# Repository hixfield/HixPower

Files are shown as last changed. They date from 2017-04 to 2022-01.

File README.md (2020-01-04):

![Build with PlatformIO](https://img.shields.io/badge/build%20with-PlatformIO-orange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)




Hardware (schematic and PCB) and software for a WIFI connected intelligent power switch. It contains a temperature sensor, PIR motion sensor, button (with LED) and buzzer and is based on the ESP8266 microcontroller. Its measurements are pubished via MQTT and it can also be controlled via MQTT. Its part of my home automation system based on a raspberry pi running Mosquitoo, Nodered, InfluxDB and Grafana.

## Improvements

- [ ] Configuration of WIFI SSID/PWD via web interface
- [ ] 3D print design to keep DS18B20 neatly in bottom of the enclosure

## Brief overview

- WIFI connected
- MQTT firmware written using PlatformIO
- plugs directly into the wall socket
- intelligently switches loads upto 2000W on/off
- measures the room temperature
- detects movement (using PIR sensor)
- button on front pannel for manual operation
- led status indication on front panel
- based on popular [ESP8266](http://esp8266.com)

# Hardware
[Click here for hardware information](hardware/README.md)
# Software
[Click here for software information](software/README.md)
# overview
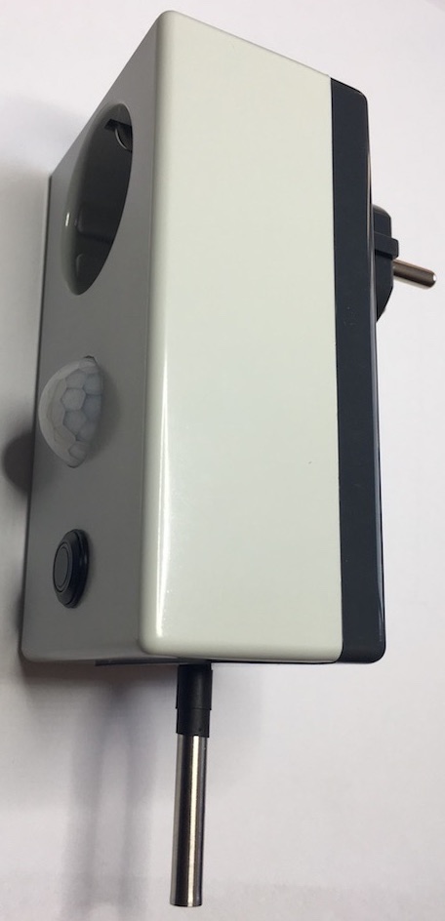
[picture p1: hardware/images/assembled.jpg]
Finished product


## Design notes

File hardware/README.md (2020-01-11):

# PCB
*(click for high resolution image)*

| Top | Bottom |
|---|---|
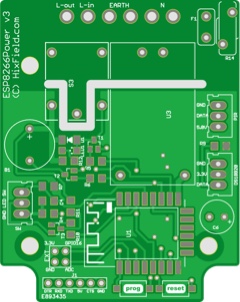
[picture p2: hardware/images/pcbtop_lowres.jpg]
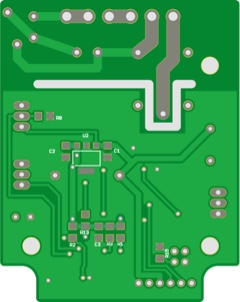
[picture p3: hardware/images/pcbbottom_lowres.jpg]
PCB bottom view
|  |  |

# Schematic
(the repository contains the EagleCAD file)
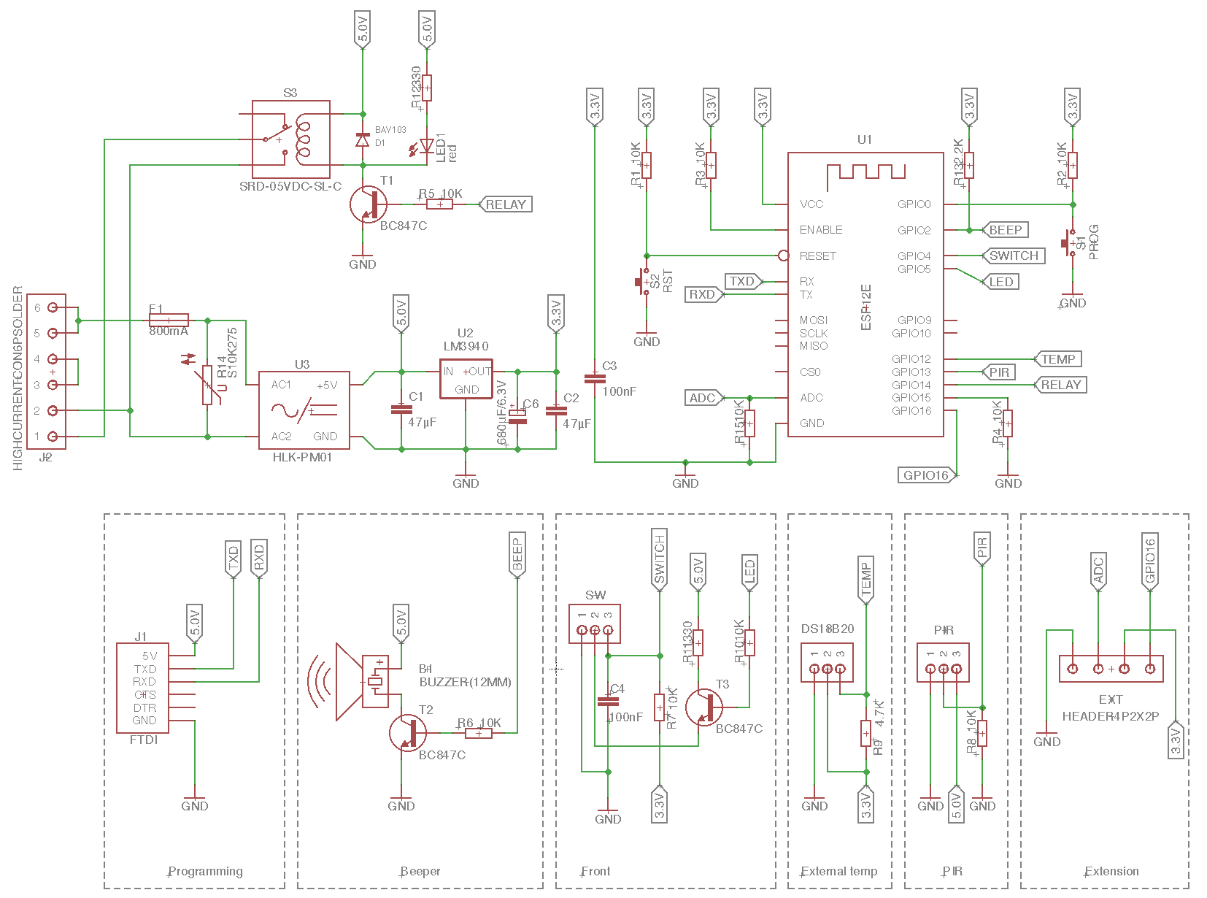
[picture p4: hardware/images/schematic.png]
image of schematic


# Components
## bill of materials
| Qty needed | Qty delivered | Part | Value | Description | picture | 
|---|---|---|---|---|---|
| 2 | 3 | C1, C2 | 47uF | SMD, tantalum capacitor, 1206 | [picture](images/1206_cap_47uf.jpg) | 
| 2 | 3 | C3, C4 | 100nF | SMD, capacitor, 1206 | [picture](images/1206_cap_100nf.jpg) | 
| 1 | 1 | C6 | 680uF / 4V | Through hole, electrolytic capacitor, diameter 8mm, 3.5mm pin spacing | [picture](images/th_cap.jpg) | 
| 10 | 11 | R1, R2, R3, R4, R5, R6, R7, R8, R10, R15 | 10K | SMD, resistor, 1206 | [picture](images/1206_res_10k.jpg) | 
| 1 | 2 | R9 | 4.7K | SMD, resistor, 1206 | [picture](images/1206_res_4.7k.jpg) | 
| 2 | 3 | R11, R12 | 330 | SMD, resistor, 1206 | [picture](images/1206_res_330.jpg) | 
| 1 | 2 | R13 | 2.2K | SMD, resistor, 1206 | [picture](images/1206_res_2.2k.jpg) | 
| 1 | 1 | R14 | S10K275 | Through hole, varistor | [picture](images/th_s10k275.jpg) | 
| 1 | 1 | F1 | 800mA | "Through hole, fuse, 8.35mm x 4 mm, 0.2"" (5.08mm) pin spacing " | [picture](images/th_fuse_800ma.jpg) | 
| 1 | 2 | LED1 | Red | SMD, led, 1206 | [picture](images/1206_led_red.jpg) | 
| 1 | 2 | D1 | BAV103 | SMD, diode, SOD80 | [picture](images/sod80_bav103.jpg) | 
| 3 | 4 | T1, T2, T3 | BC847C | SMD, NPN Transistor, SOT23 | [picture](images/sot23_bc847c.jpg) | 
| 1 | 1 | B1 | 5V | "Through hole, buzzer, diameter 12mm, 0.3"" (7.62mm) pin spacing" | [picture](images/th_buzzer.jpg) | 
| 1 | 1 | U1 | ESP12E | SMD, ESP12E module | [picture](images/esp12e.jpg) | 
| 1 | 1 | U2 | LM3940 | SMD, Low drop voltage regulator, SOT223 | [picture](images/sot223_lm3940.jpg) | 
| 1 | 1 | U3 | HLK-PM01 | Through hole, power module, HiLink HLK-PM01 | [picture](images/th_hlk-pm01.jpg) | 
| 1 | 1 | J1 | FTDI | "Through hole, header female,  6P,  0.1"" (2.54mm) pin spacing" | [picture](images/th_ftdi.jpg) | 
| 2 | 2 | S1, S2 | PROG, RST | SMD Push button | [picture](images/micropushbutton.jpg)  | 
| 1 | 1 | S3 | SRD-05VDC-SL-C | Through hole, Relay SRD-05VDC-SL-C | [picture](images/relay.jpg) | 
| 2 | 2 | PIR, SW | XH3P | Through hole, Connector male XH3P straight | [picture](images/th_xh3pmale.jpg) | 
| 1 | 1 | DS18B20 temp sensor encased | | Module, DS18B20 temp sensor encased | [picture](images/ds18b20.jpg) | 
| 1 | 1 | PIR Module | | Module, PIR | [picture](images/pirmodule.jpg) | 
| 1 | 1 | Switch with led | | Switch with led | [picture](images/pushbutton.jpg) | 
| 2 | 2 | XH3P female no pins | | XH3P female no pins | [picture](images/xh3pfemalesolder.jpg) | 
| 2 | 2 | XH3P wire 10cm [pin -> solder], black | | XH3P wire 10cm [pin -> solder], black | [picture](images/xh3pfemalesolder.jpg) | 
| 1 | 1 | XH3P wire 10cm [pin -> solder], red | | XH3P wire 10cm [pin -> solder], red | [picture](images/xh3pfemalesolder.jpg) | 
| 1 | 1 | XH3P wire 10cm [pin -> solder], yellow | | XH3P wire 10cm [pin -> solder], yellow | [picture](images/xh3pfemalesolder.jpg) | 
| 2 | 2 | XH3P wire 10cm [pin -> solder], white | | XH3P wire 10cm [pin -> solder], white | [picture](images/xh3pfemalesolder.jpg) | 
| 1 | 1 | Case | | Case BOPLA 43432501, predrilled | [picture](images/case.jpg) | 
| 1 | 1 | PCB | | Custom PCB | [picture](images/pcb.jpg) | 
| 2 | 2 | Cable lug round M3 | | Cable lug round M3 | [picture](images/cablelugroundm3.jpg)  | 
| 1 | 1 | Cable lug fork M4 | | Cable lug fork M4 | [picture](images/cablelugforkm4.jpg) | 
| 1 | 1 | Heat shrink tubing 1,5mm, 2.5mm, 6mm, 8mm| | Heat shrink tubing 1,5mm, 2.5mm, 6mm, 8mm | [picture](images/heatshrinktubing.jpg) | 
| 3 | 3 | PCB Fixation screw | | Allen screw, inox, M3 x 6mm thread length | [picture](images/screw.jpg) | 
| 1 | 1 | 1.5mm2 x 55mm mains wire brown | | 1.5mm2 x 55mm mains wire brown | [picture](images/mainswire.jpg) | 
| 1 | 1 | 1.5mm2 x 55mm mains wire blue | | 1.5mm2 x 55mm mains wire blue | [picture](images/mainswire.jpg) | 
| 1 | 1 | 1.5mm2 x 55mm mains wire yellow/green | | 1.5mm2 x 55mm mains wire yellow/green | [picture](images/mainswire.jpg) | 

## overview
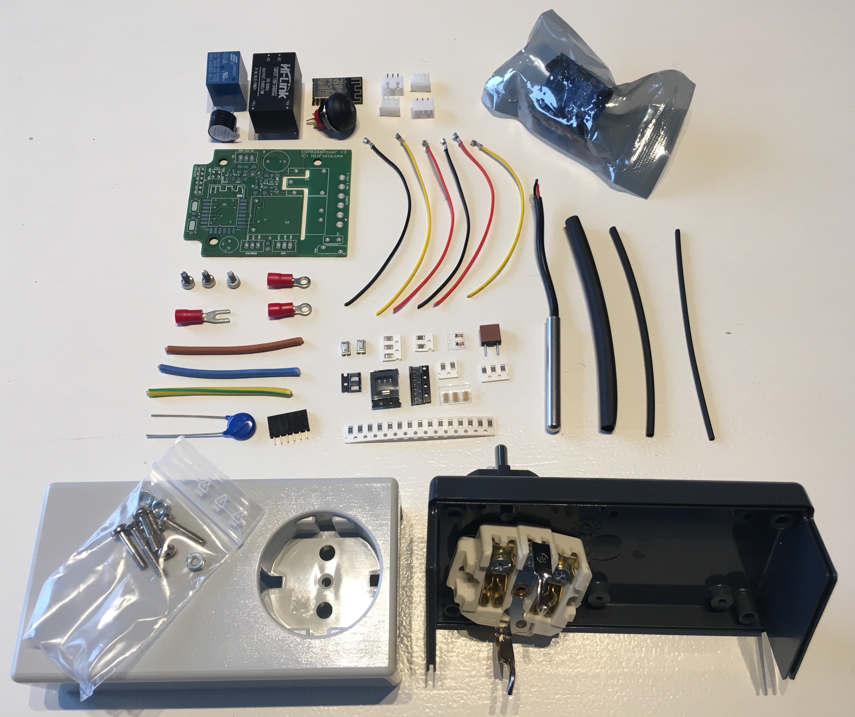
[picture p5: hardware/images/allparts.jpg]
all parts


# Assembly instructions
## soldering of the PCB
### Step 0: BC847 transistors
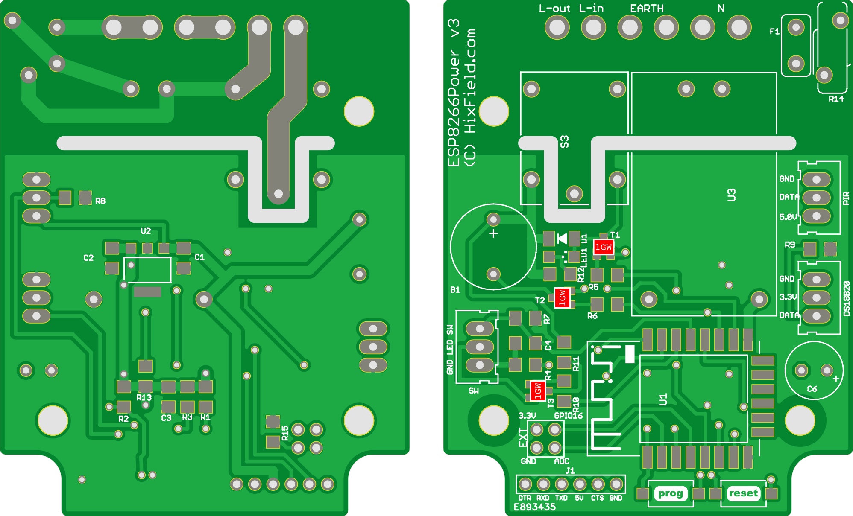
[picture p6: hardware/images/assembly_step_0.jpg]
assembling step 1

### Step 1: 10K resistors
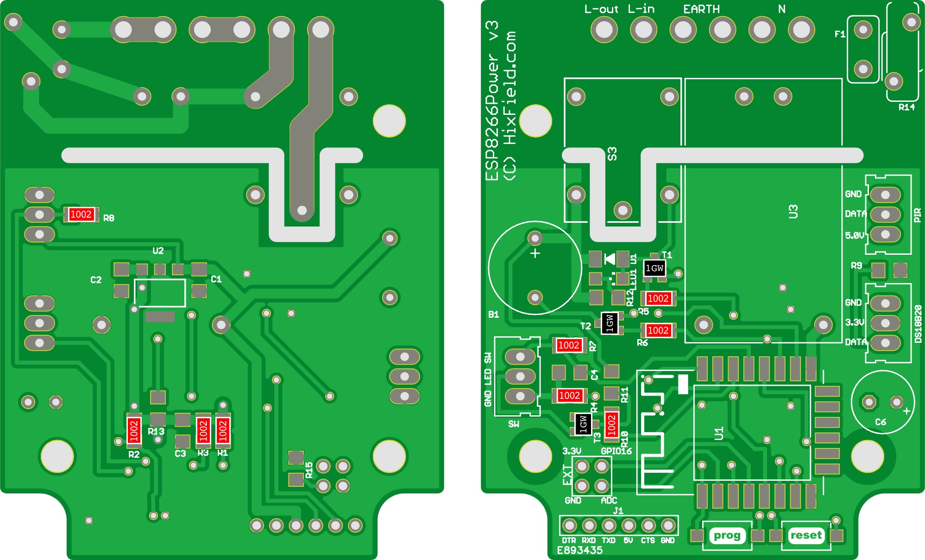
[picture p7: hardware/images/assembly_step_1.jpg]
assembling step 1

### Step 2: 4.7K resistors
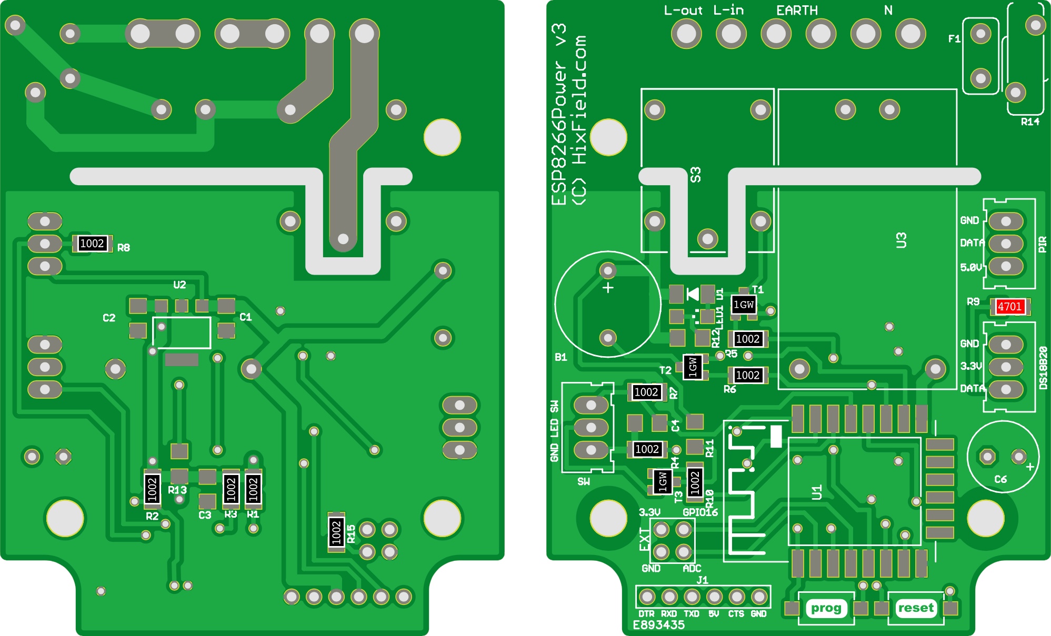
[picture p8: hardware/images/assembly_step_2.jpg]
assembling step 1

### Step 3: 330 resistors
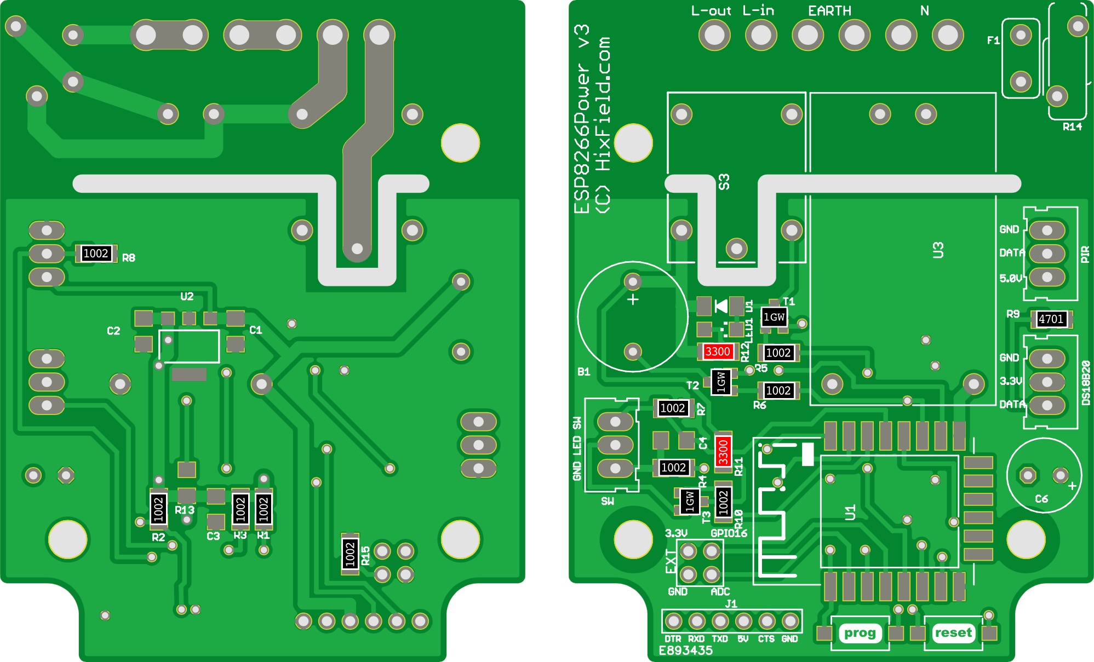
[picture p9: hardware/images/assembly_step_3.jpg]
assembling step 1

### Step 4: 2.2K resistors
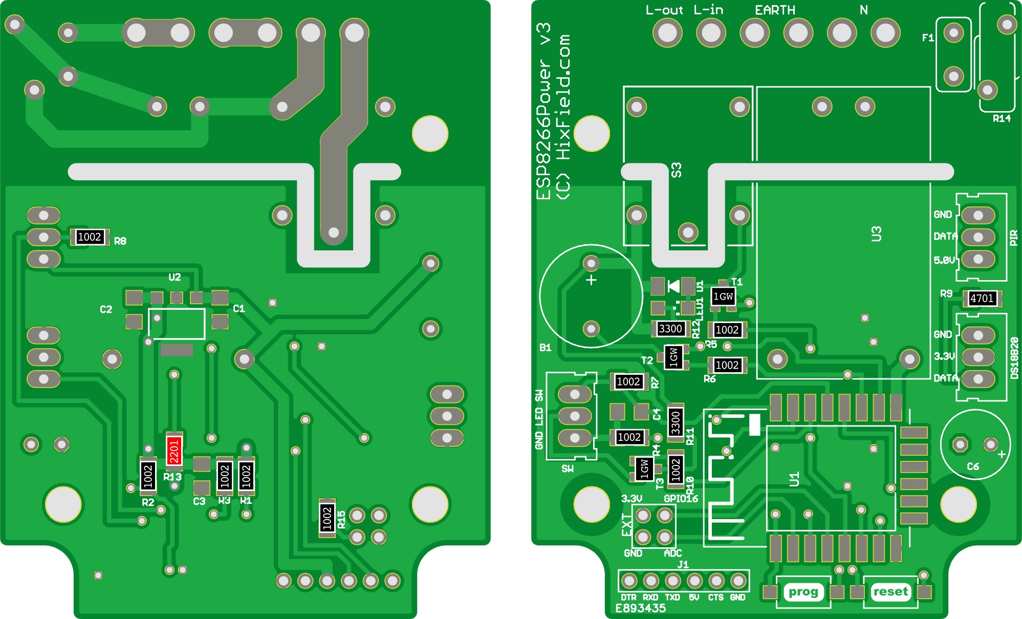
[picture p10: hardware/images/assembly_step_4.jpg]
assembling step 1

### Step 5: 100nF capacitors
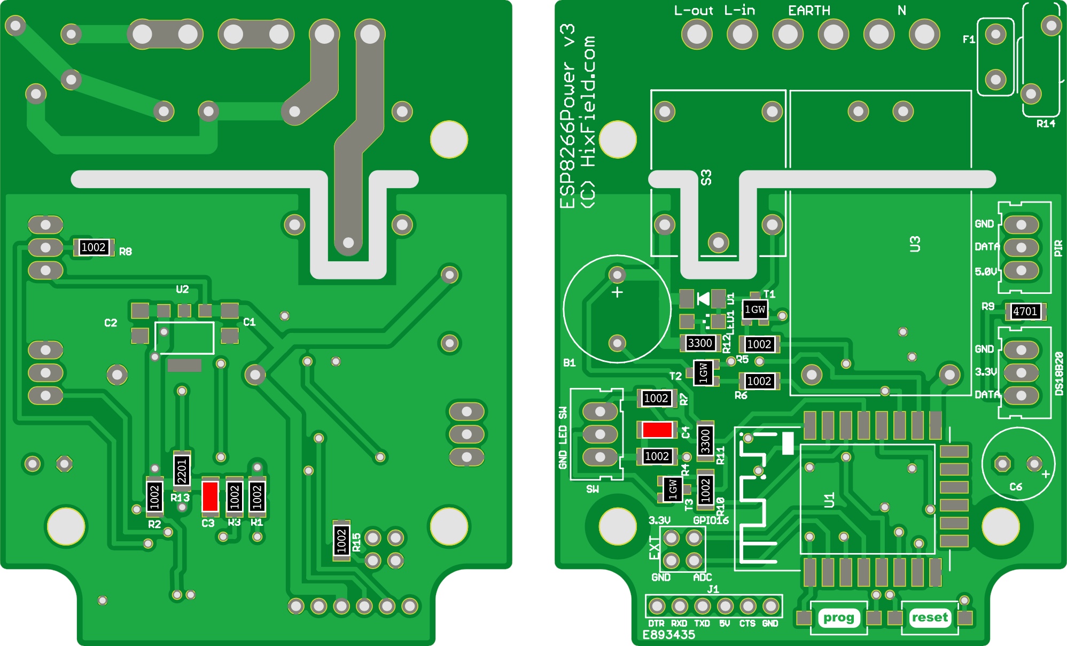
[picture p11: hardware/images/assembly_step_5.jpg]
assembling step 1

### Step 6: 47uF tantalum capacitors
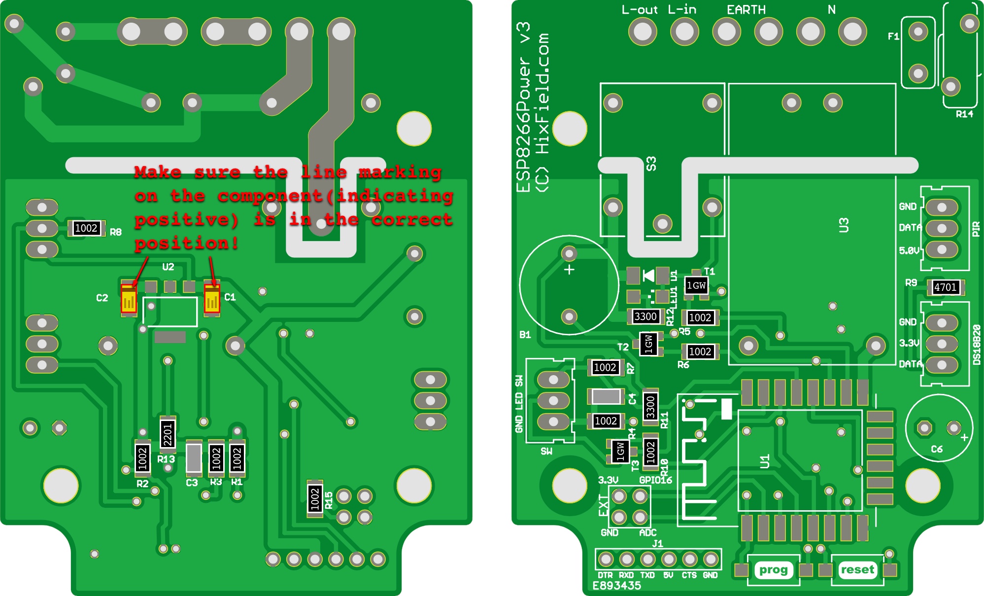
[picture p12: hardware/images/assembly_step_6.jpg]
assembling step 1

### Step 7: LM3940 voltage controller
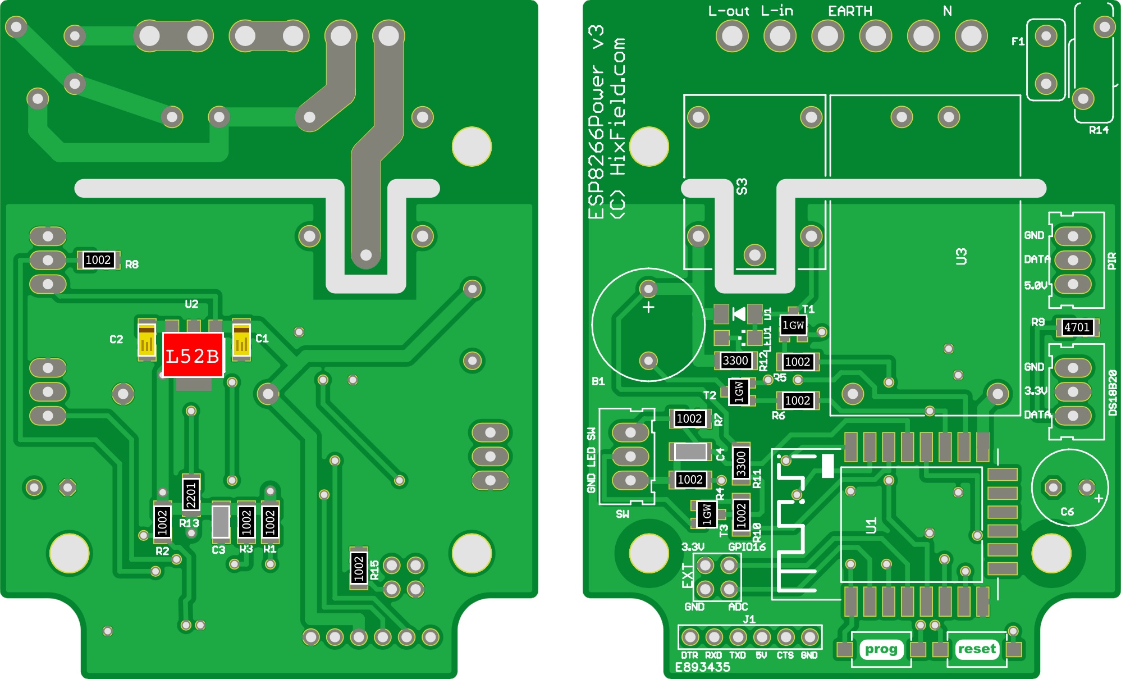
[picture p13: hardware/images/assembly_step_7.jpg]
assembling step 1

### Step 8: LED
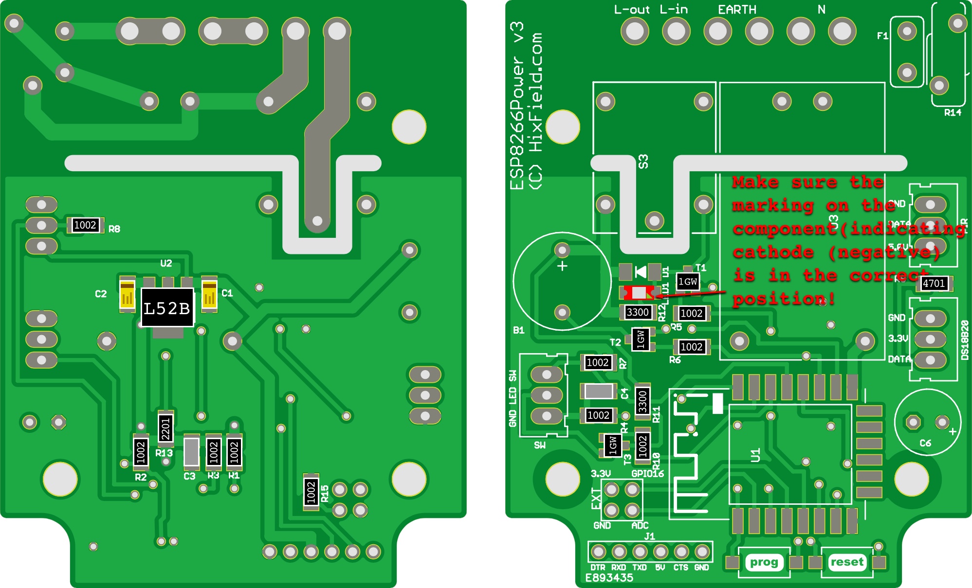
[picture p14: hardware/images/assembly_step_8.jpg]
assembling step 1

### Step 9: Diode
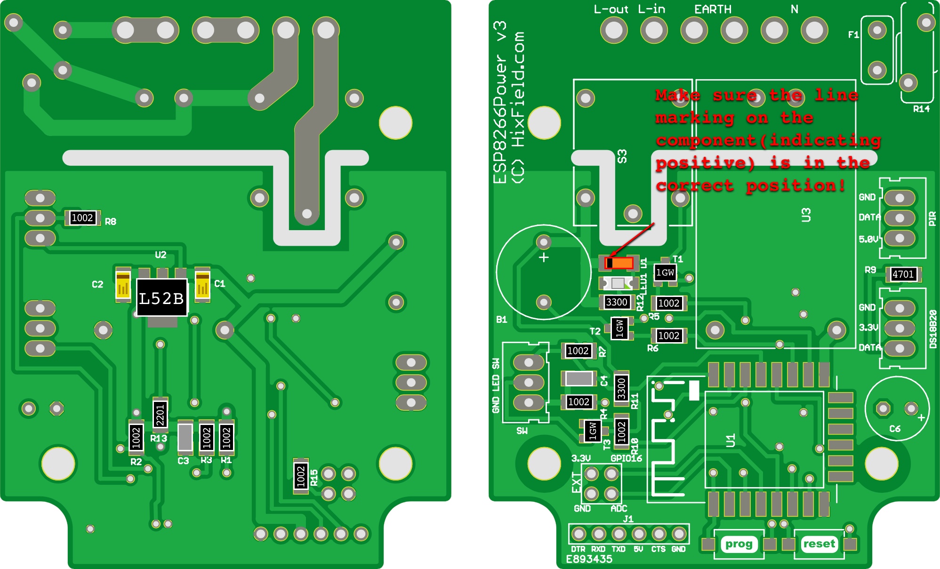
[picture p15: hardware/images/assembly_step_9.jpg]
assembling step 1

### Step 10: ESP12E
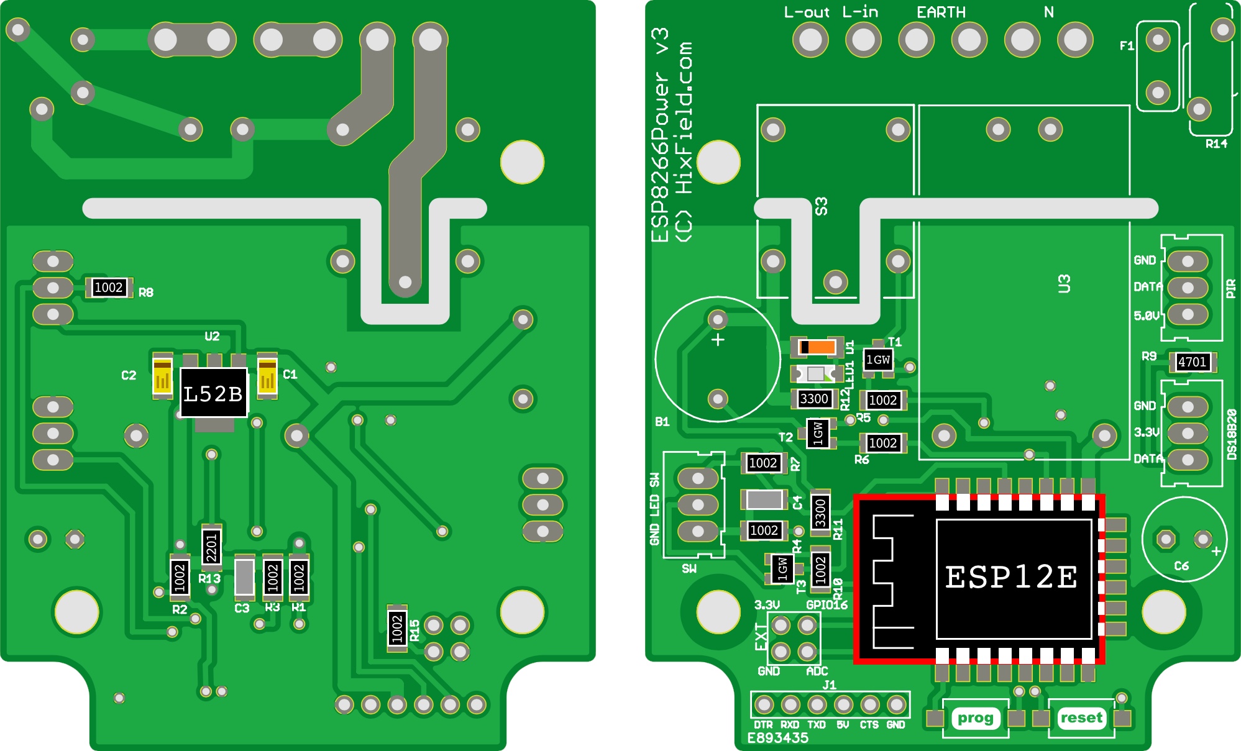
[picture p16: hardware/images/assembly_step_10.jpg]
assembling step 1

### Step 11: Push buttons
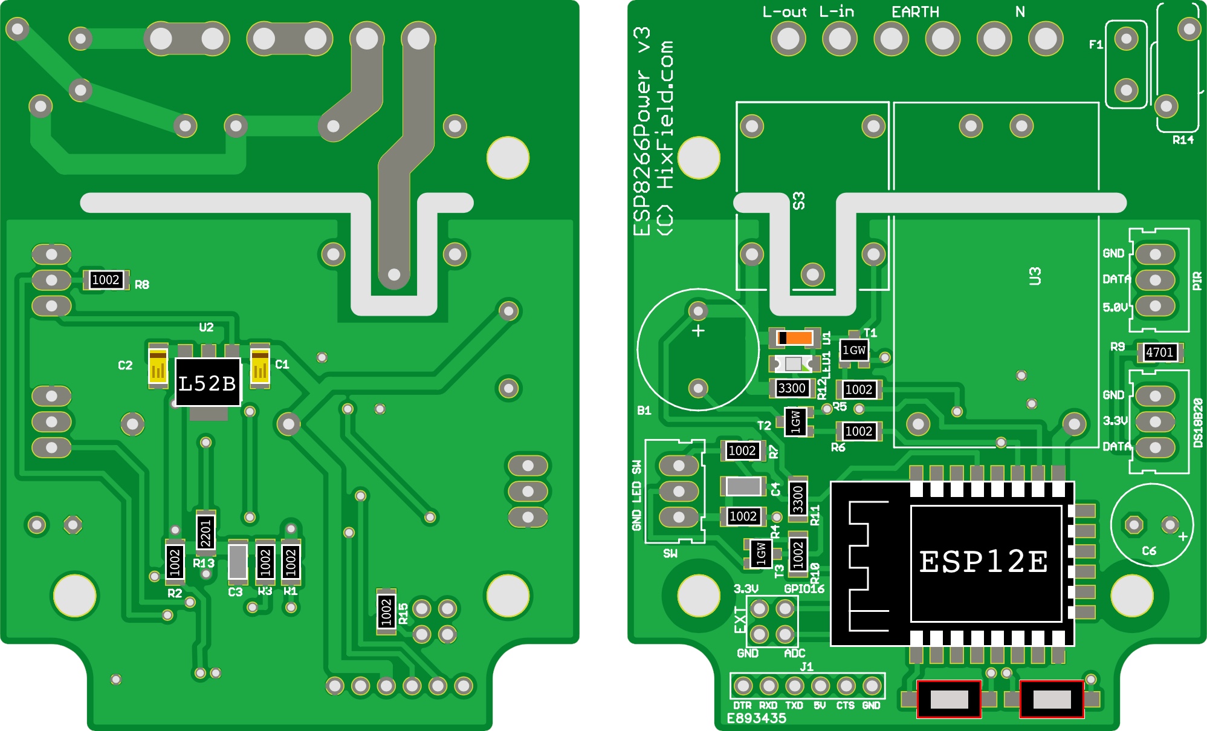
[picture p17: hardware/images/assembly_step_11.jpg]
assembling step 1

### Step 12: 680uF capacitor 
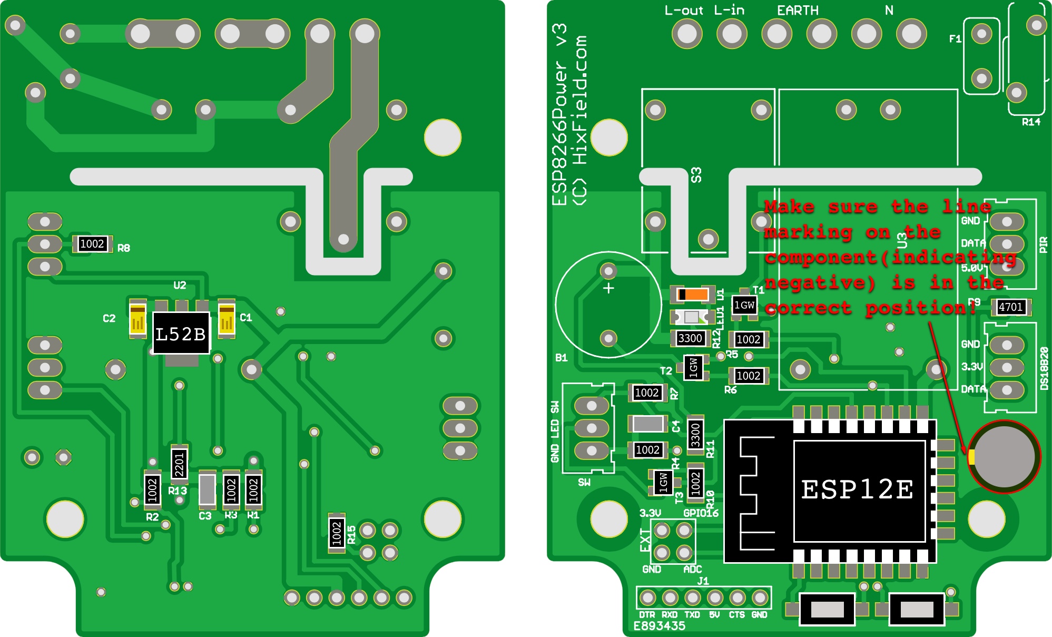
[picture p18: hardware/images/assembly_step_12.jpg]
assembling step 1

### Step 13: connectors
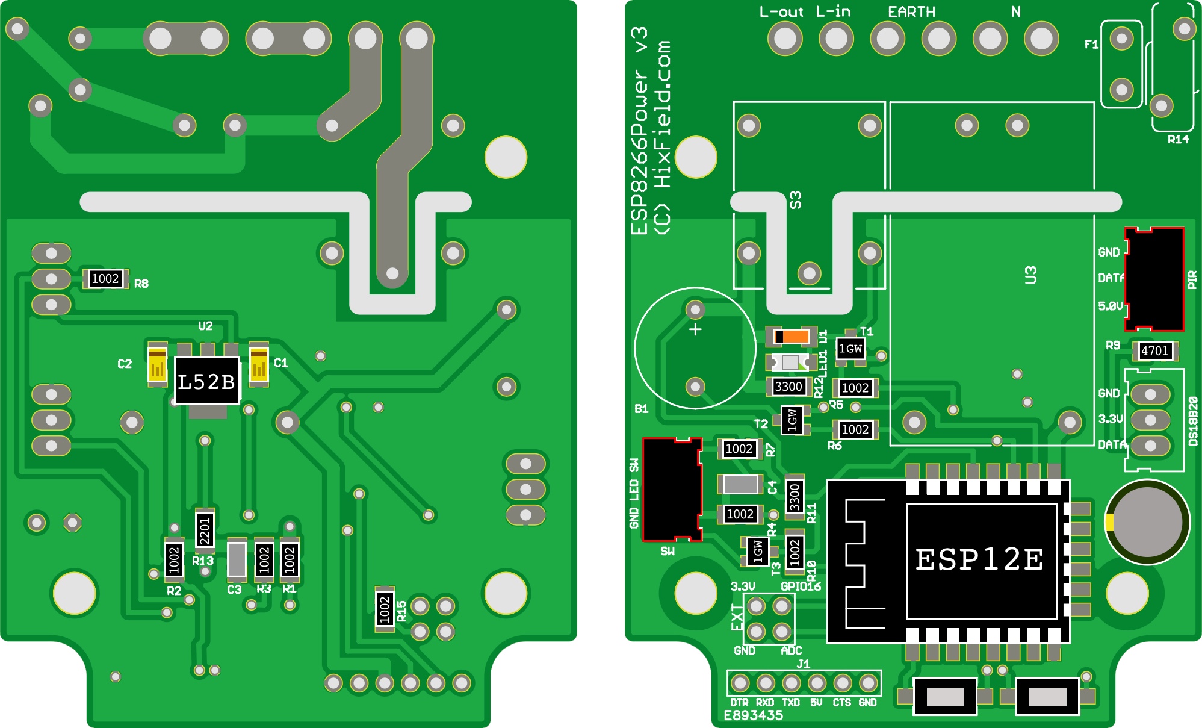
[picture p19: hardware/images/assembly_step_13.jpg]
assembling step 1

### Step 14: buzzer
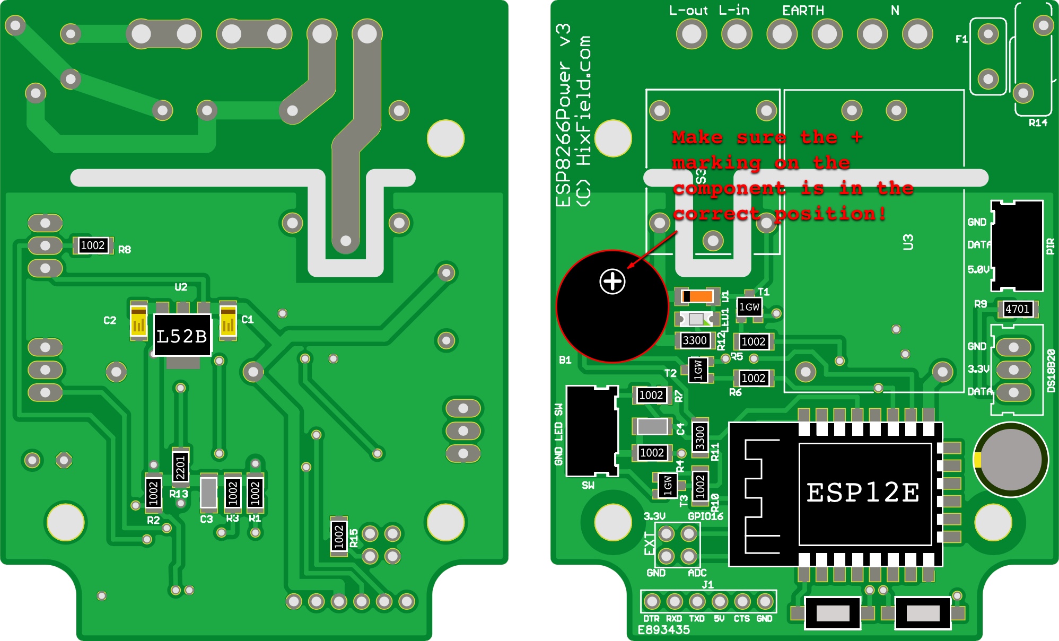
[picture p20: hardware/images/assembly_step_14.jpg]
assembling step 1

### Step 15: relay
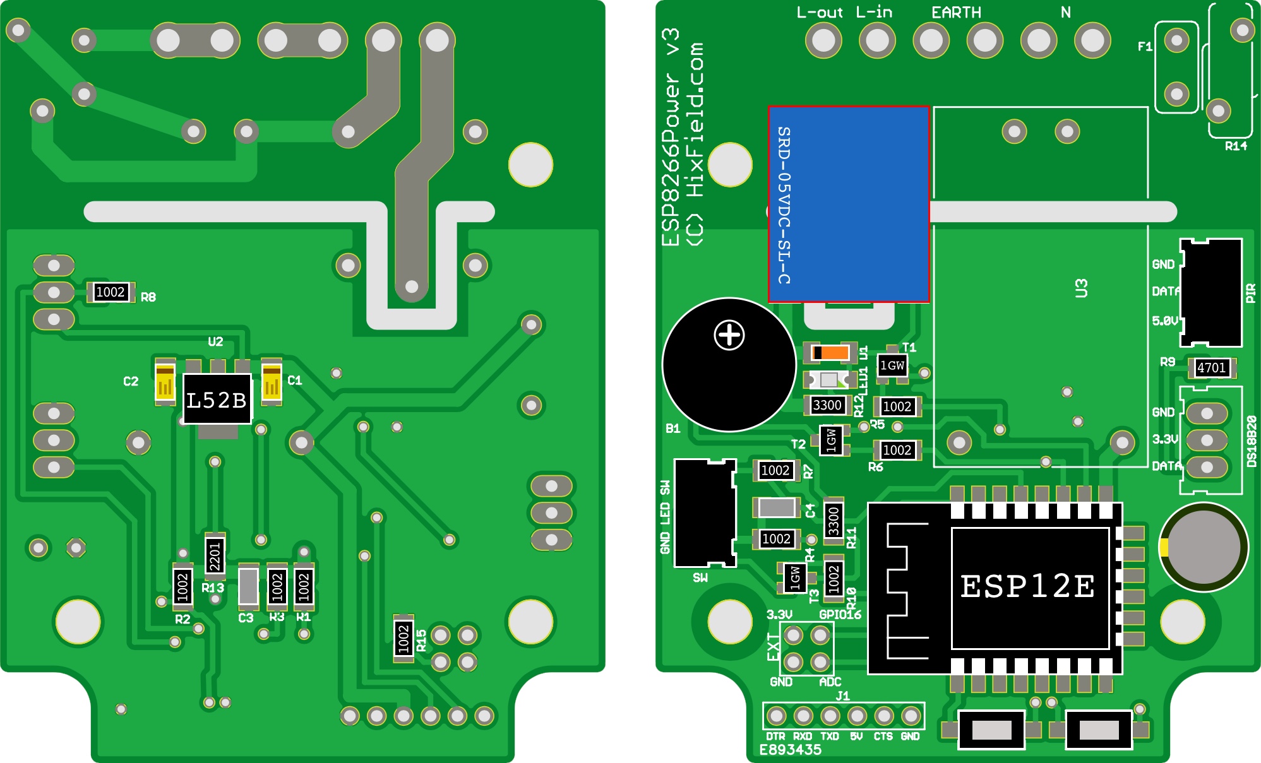
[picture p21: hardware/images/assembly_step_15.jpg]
assembling step 1

### Step 16: power supply
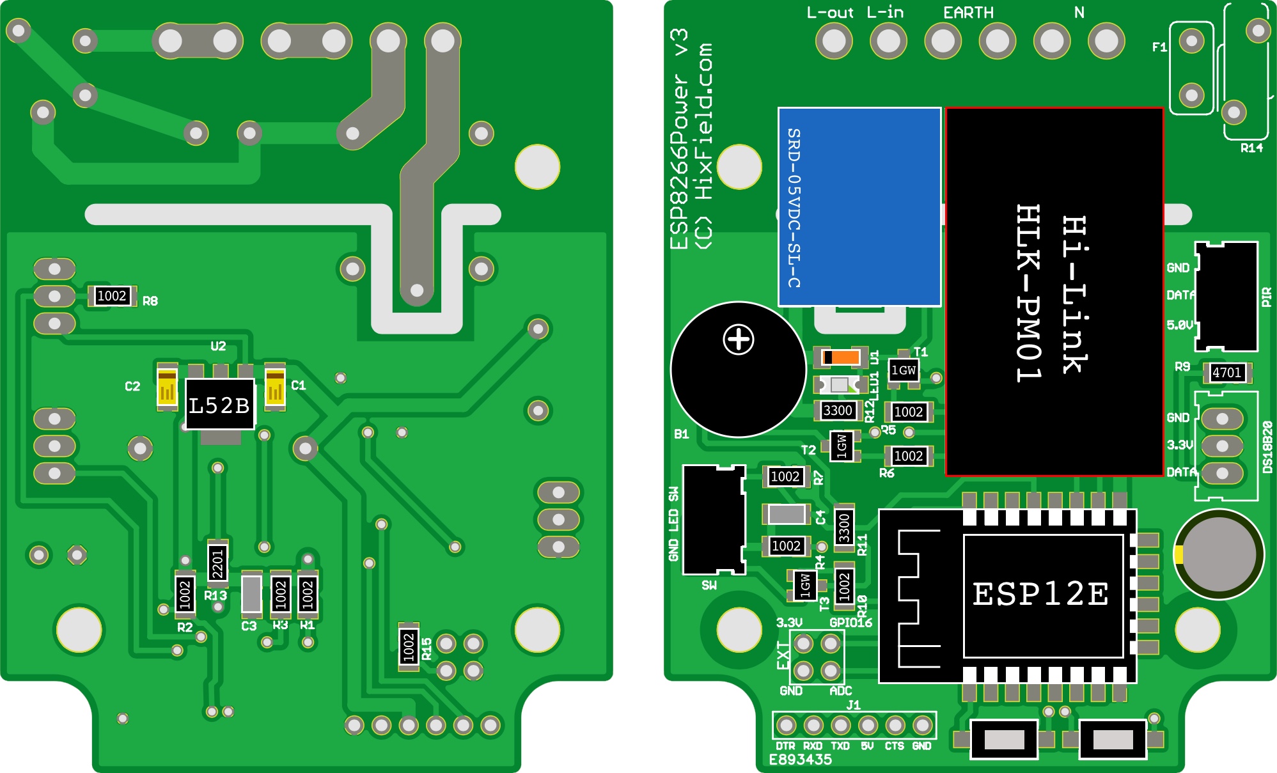
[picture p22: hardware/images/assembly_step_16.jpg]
assembling step 1

### Step 17: FTDI connector
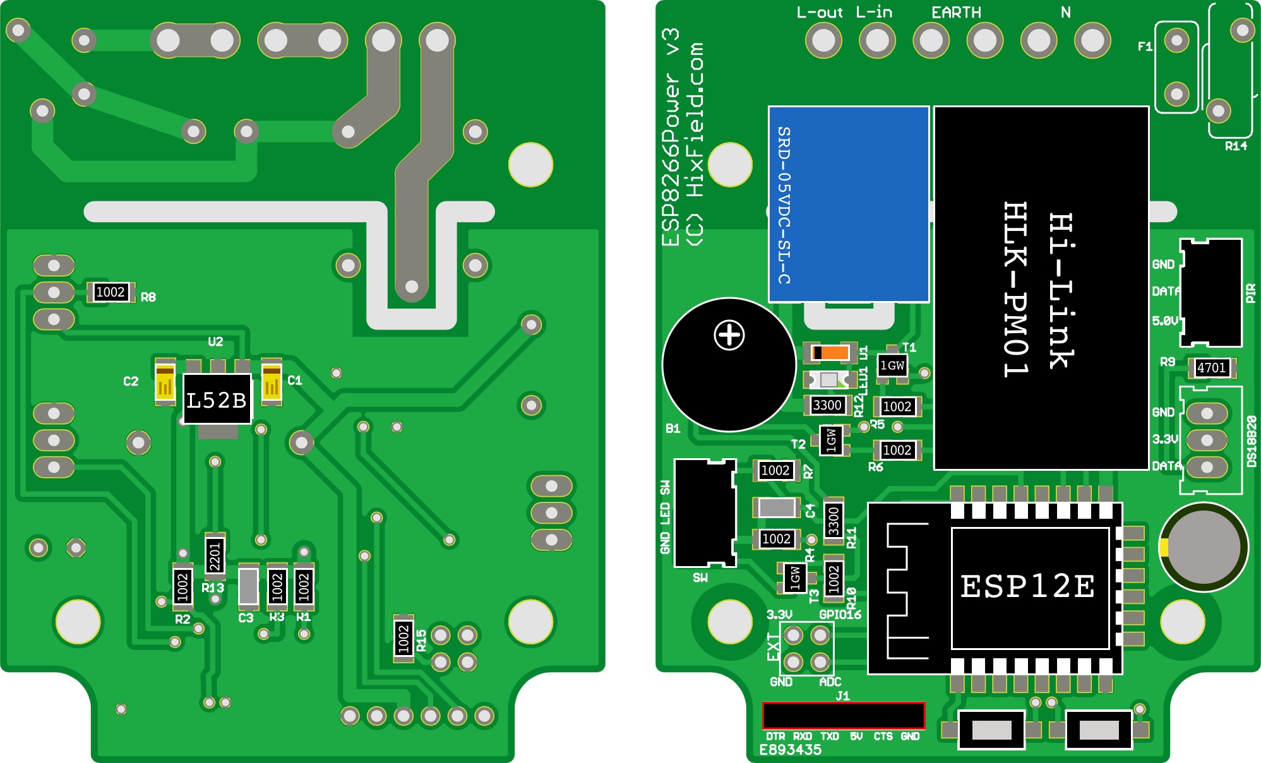
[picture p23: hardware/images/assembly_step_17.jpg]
assembling step 1

### Step 18: Fuse
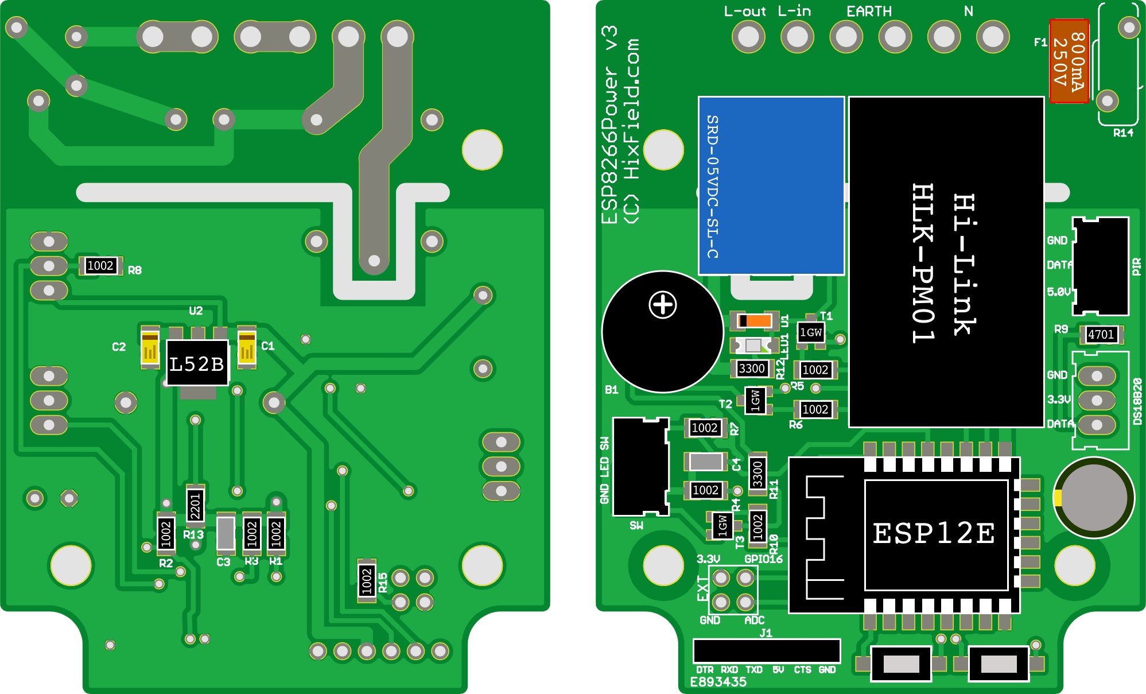
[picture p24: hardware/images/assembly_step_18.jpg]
assembling step 1

### Step 19: Varistor
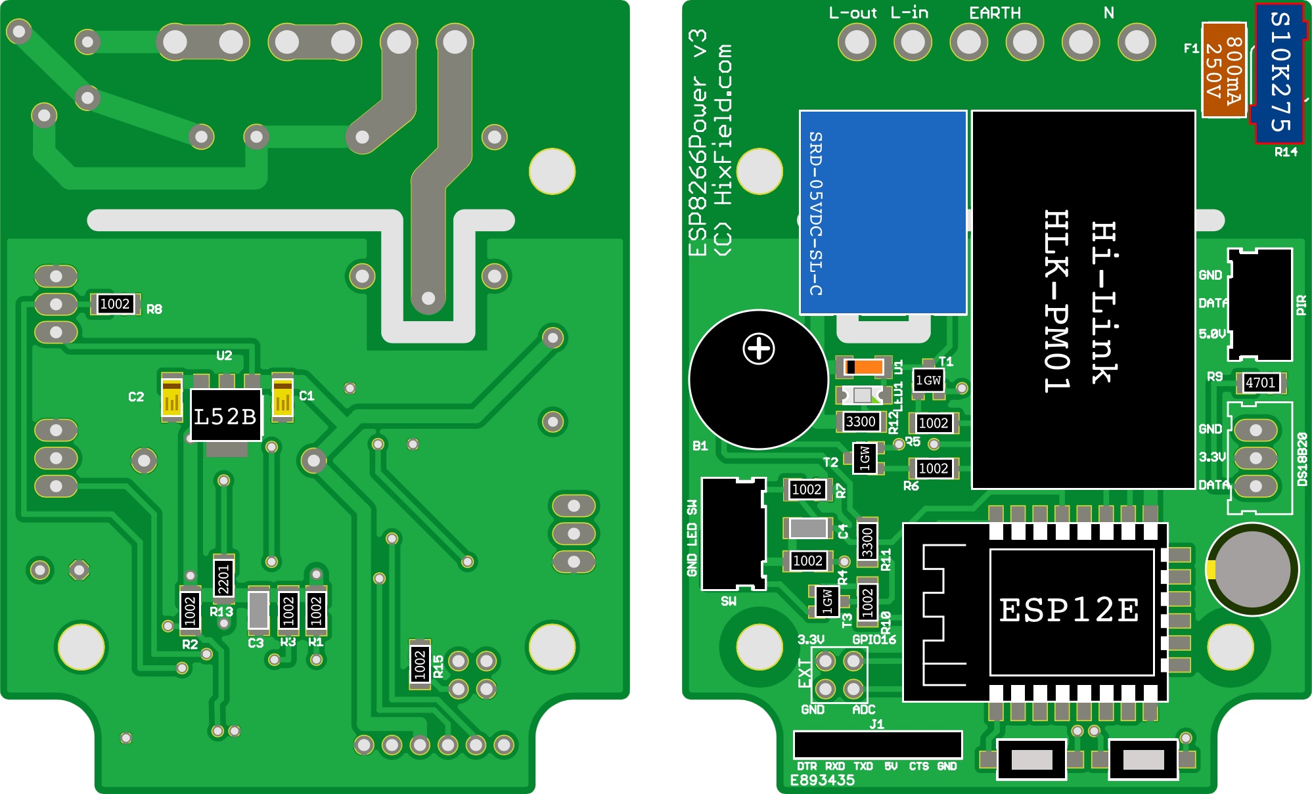
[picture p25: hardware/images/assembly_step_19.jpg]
assembling step 1

## Assemble main wires
### Step 29: neutral (blue) and live (brown) mains connection wires
1.5 mm² x 70 mm
assembling step 1
### Step 21: earthing wire (yellow/green)
assembling step 1
## Assemble push button
### Step 22: prepare wires
assembling step 1
### Step 23: connect (black) GND wire
assembling step 1
### Step 24: connect (white) SWITCH wire
assembling step 1
### Step 25: connect (yellow) + LED wire
assembling step 1
### Step 26: shrink and put in housing
assembling step 1
## Assemble PIR
### Step 27: prepare and connect wires
assembling step 1
### Step 28: shrink and put in housing
assembling step 1
### Step 29: adjust settings
assembling step 1

- refer to [HC-SR501 Motion Sensor Tutorial]([http://henrysbench.capnfatz.com/henrys-bench/arduino-sensors-and-input/arduino-hc-sr501-motion-sensor-tutorial/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]) http://henrysbench.capnfatz.com/henrys-bench/arduino-sensors-and-input/arduino-hc-sr501-motion-sensor-tutorial/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
- trigger selection jumper => recommended REPEATABLE TRIGGER
- set correct sensitivy and delay setings (variable resistors)
 * Sensitivity Adjust => recommended MIDDLE
 * Time Delay Adjust  => recommended MINIMUM

## Prepare temperature sensor
assembling step 1

##Build PCB in the case
- solder the temperature sensor to the pcb
 - red = 3.3v
 - black = GND
 - blue = DATA  
- put PCB in case and fix using the screws
- put the temp sensor through the hole in the case
- connect the mains and earth wires to the power pins in the case
- cut 10 mm of heat shrink tube 8mm and slide it over the temperature sensor to fix it

## Programming via the FTDI connector
If you want to program manually via the FTDI connector:

- DO NOT 	PLUG THE DEVICE IN THE POWER !
- put in your USB -> SERIAL connector
- Push the onboard buttons in the correct sequence:
 - push and keep pushing the PROG button
 - push the RESET (while keeping PROG pressed)
 - release both butons
- De device is now in programming mode 	

##Assemble front
- mount the push button in the front of the case
- fix / glue the PIR sensor in the front of the case

##Assemble the device
- assemble front and back of case
 - connect push button connector
 - connect PIR connector
- close case and put in the screws  

# Packaging
- 330 gr (including box)
- ideal box would be approx 70mm x 130mm x 100 mm
# Case preparation
PCB top view

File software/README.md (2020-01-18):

![Build with PlatformIO](https://img.shields.io/badge/build%20with-PlatformIO-orange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)


# HixPower

Software for a WIFI connected intelligent power switch. It contains a temperature sensor, PIR/radar motion sensor, button (with LED) and buzzer and is based on the ESP8266 microcontroller. Its measurements are pubished via MQTT and it can also be controlled via MQTT. Its part of my home automation system based on a raspberry pi running Mosquitoo, Nodered, InfluxDB and Grafana.

## High voltage

This device uses high mains voltage! Remove it from the mains power (socket) while programming via the onboard FTDI connector. During programming and debugging the device can safely be powered via the FTDI with 5V. It will boot and work normally drawing power over the FTDI. This way you can also debug using the onboard serial port for the ESP8266 environment.

Make sure your FTDI programmer can deliver the required power. Mine, a chinese clone "Deek-Robot" had no problem at all.
Once initially flashed the device can be updated Over The Air (OTA) (as supported by this firmware).

## MQTT

### Publishing

```
{room}
   └─── HixCO2
           └─── {deviceTag}
                     └─── device
                     │       └─── count
                     │       └─── room
                     │       └─── device_type
                     │       └─── device_version
                     │       └─── device_tag
                     │       └─── device_name
                     │       └─── wifi_ssid
                     │       └─── wifi_ip
                     │       └─── desired_temperature
                     │       └─── auto_switchoff_seconds
                     │       
                     └─── status
                     │       └─── count
                     │       └─── wifi_rssi
                     │       └─── temperature
                     │       └─── motion_detected
                     │       └─── switch_pressed
                     │       └─── beeper_on
                     │       └─── output_allowed
                     │       └─── output_on
                     │       └─── auto_switchoff_seconds_left
                     │
                     └─── subscribe
                     │       └─── desired_temperature
                     │       └─── auto_switchoff_seconds
                     │       └─── output_toggle
                     │
                     └─── influxdb
```

### Subscribing
This device listens to the above depicted topics to set the desired temperature, auto switch off timeout and you can switch it on/off (toggle).

#### `influxdb` topic publishing contents
To make the import in the influxdb from Node-RED as easy as possible the `influxdb` topic publishes a json document that can immediatly imported using the `influxdb in` node.
They only thing required is to convert it to a json object via the `To json` node.
Node-RED influxDB import

Following the `influxdb in` node the json is an array where:

- the first element contains the measurements
- the second element contains the tags

```
[  
   {  
      "wifi_rssi"                   : -45,
      "temperature"                 : 45,
      "motion_detected"             : true,
      "switch_pressed"              : false,
      "beeper_on"                   : false,
      "output_allowed"              : true,
      "output_on".                  : true,
      "auto_switchoff_seconds_left" : 768
   },
   {  
      "device_type".                 : "HixPower",
      "device_version".              : "2.2.9",
      "device_tag".                  : "heating",
      "room"                         : "bathroom",
      "wifi_ssid".                   : "public_wifi",
      "desired_temperature".         : "public_wifi",
      "auto_switchoff_seconds_left". : "public_wifi"
   }
]
```

## Configuration web interface

Config web interface

* Once connectted to the WIFI a normal browser can be used to configure the MQTT details.
* Just go the the device's ip address with your browser
* Password is intitially set as `bornem1973`.
* At this moment the WIFI SSID and password are hardcoded in the src/secret.cpp file

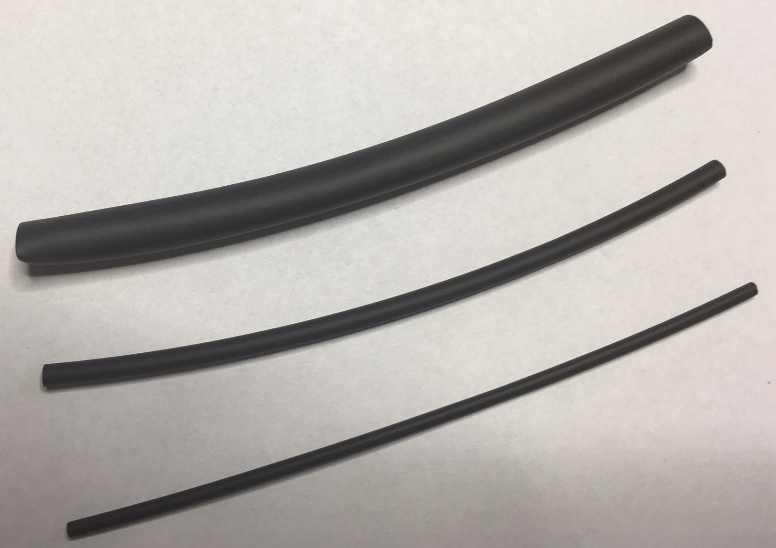
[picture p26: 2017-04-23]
hardware/images/heatshrinktubing.jpg

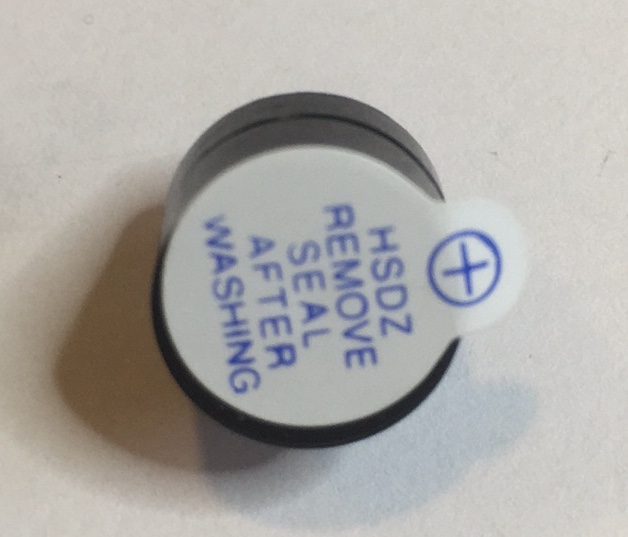
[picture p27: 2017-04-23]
hardware/images/th_buzzer.jpg

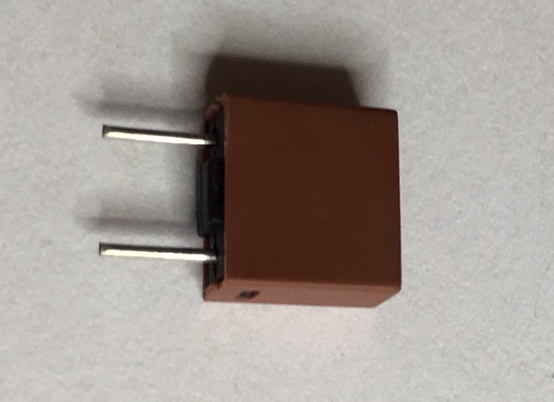
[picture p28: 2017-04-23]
hardware/images/th_fuse_800ma.jpg

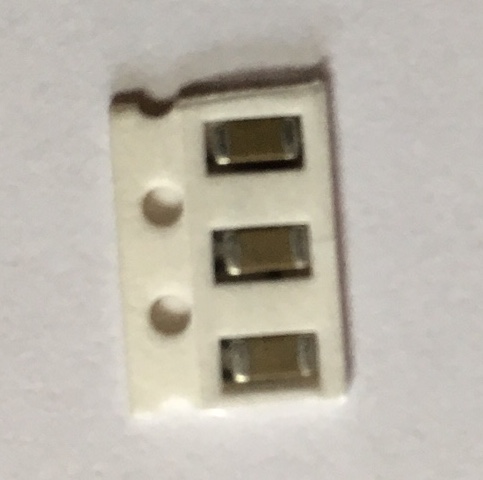
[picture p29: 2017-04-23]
hardware/images/1206_cap_100nf.jpg

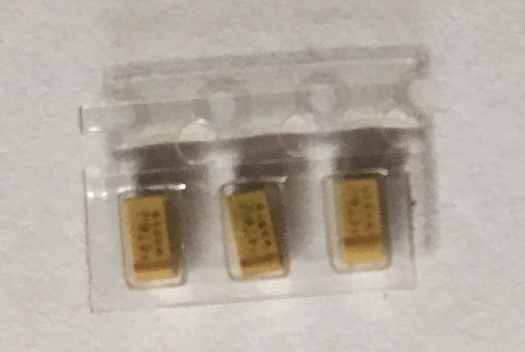
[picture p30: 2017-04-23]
hardware/images/1206_cap_47uf.jpg

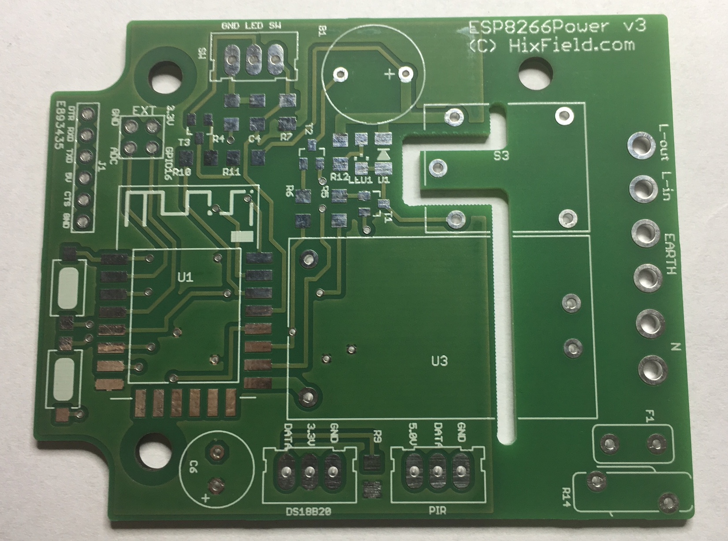
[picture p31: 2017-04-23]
hardware/images/pcb.jpg

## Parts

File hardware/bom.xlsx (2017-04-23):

price excl | subtotal | Qty needed | Qty delivered | Part | Value | Description | picture | picture | Manufacturer | Manufacturer description | link | Device (Eagle) | Package | Description
0.100 € | 0.200 € | 2 | 3 | C1, C2 | 47uF | SMD, tantalum capacitor, 1206 | [picture](images/1206_cap_47uf.jpg) | 1206_cap_47uf.jpg | aliexpress | 47uF 6.3V 1206 SMD Tantalum Capacitor +/-20% A Type | https://www.aliexpress.com/item/47uF-6-3V-1206-SMD-Tantalum-Capacitor-20-A-Type/32321374266.html | C-EUC1206 | C1206 | CAPACITOR, European symbol
0.009 € | 0.017 € | 2 | 3 | C3, C4 | 100nF | SMD, capacitor, 1206 | [picture](images/1206_cap_100nf.jpg) | 1206_cap_100nf.jpg | aliexpress | Free shipping 1206 SMD capacitor 100nf 50V 104Z 200pcs | https://www.aliexpress.com/item/Free-shipping-1206-SMD-capacitor-100nf-50V-104Z-100PCS/32372347509.html | C-EUC1206 | C1206 | CAPACITOR, European symbol
0.056 € | 0.056 € | 1 | 1 | C6 | 680uF / 4V | Through hole, electrolytic capacitor, diameter 8mm, 3.5mm pin spacing | [picture](images/th_cap_470uf.jpg) | th_cap_470uf.jpg | aliexpress | Free shipping 100PCS 4V 680UF Aluminum electrolytic capacitors 680uF 4V 8*8mm Good quality | https://www.aliexpress.com/item/Free-shipping-100PCS-4V-680UF-Aluminum-electrolytic-capacitors-680uF-4V-8-8mm-Good-quality/32323856831.html | CPOL-EUE3.5-8 | E3,5-8 | POLARIZED CAPACITOR, European symbol
0.004 € | 0.038 € | 10 | 11 | R1, R2, R3, R4, R5, R6, R7, R8, R10, R15 | 10K | SMD, resistor, 1206 | [picture](images/1206_res_10k.jpg) | 1206_res_10k.jpg | aliexpress | 500pcs 1206 SMD Resistor 1% 10K ohm | https://www.aliexpress.com/store/product/1206-SMD-Resistor-5-10K-ohm-5000pcs-lot/506373_32307467056.html | R-EU_R1206 | R1206 | RESISTOR, European symbol
0.004 € | 0.004 € | 1 | 2 | R9 | 4.7K | SMD, resistor, 1206 | [picture](images/1206_res_4.7k.jpg) | 1206_res_4.7k.jpg | aliexpress | 500pcs 1206 SMD Resistor 1% 4.7 ohm | https://www.aliexpress.com/store/product/1206-SMD-Resistor-5-4-7-ohm-5000pcs-lot/506373_32308252416.html | R-EU_R1206 | R1206 | RESISTOR, European symbol
0.004 € | 0.008 € | 2 | 3 | R11, R12 | 330 | SMD, resistor, 1206 | [picture](images/1206_res_330.jpg) | 1206_res_330.jpg | aliexpress | 500pcs 1206 SMD Resistor 1% 330 ohm | https://www.aliexpress.com/item/1206-SMD-Resistor-5-330-ohm-5000pcs-lot/32307463025.html | R-EU_R1206 | R1206 | RESISTOR, European symbol
0.004 € | 0.004 € | 1 | 2 | R13 | 2.2K | SMD, resistor, 1206 | [picture](images/1206_res_2.2k.jpg) | 1206_res_2.2k.jpg | aliexpress | 500pcs 1206 SMD Resistor 1% 2.2K ohm | https://www.aliexpress.com/store/product/1206-SMD-Resistor-5-2-2K-ohm-5000pcs-lot/506373_32307467027.html | R-EU_R1206 | R1206 | RESISTOR, European symbol
0.280 € | 0.280 € | 1 | 1 | R14 | S10K275 | Through hole, varistor | [picture](images/th_s10k275.jpg) | th_s10k275.jpg | conrad | Schijfvaristor S10K275 430 V Epcos S10K275 1 stuks | http://www.conrad.be/ce/nl/product/500592/Schijfvaristor-S10K275-430-V-Epcos-S10K275-1-stuks/SHOP_AREA_17441 | S10K275 | S10K275 | VARISTOR
0.270 € | 0.270 € | 1 | 1 | F1 | 800mA | Through hole, fuse, 8.35mm x 4 mm, 0.2" (5.08mm) pin spacing | [picture](images/th_fuse_800ma.jpg) | th_fuse_800ma.jpg | conrad | ESKA 883116 Printzekering Radiaal bedraad Hoekig 800 mA 250 V Traag -T- 1 stuks | http://www.conrad.be/ce/nl/product/537512/ESKA-883116-Printzekering-Radiaal-bedraad-Hoekig-800-mA-250-V-Traag-T-1-stuks/SHOP_AREA_17392 | FUSE | FUSE_508 | FUSE
0.010 € | 0.010 € | 1 | 2 | LED1 | Red | SMD, led, 1206 | [picture](images/1206_led_red.jpg) | 1206_led_red.jpg | aliexpress | 100PCS/LOT 1206 Red SMD LED Diode Light 3216 Diodes SMD Super Bright 1206 led 3.2*1.6mm Red Color New | https://www.aliexpress.com/item/100PCS-LOT-1206-Red-SMD-LED-Diode-Light-3216-Diodes-SMD-Super-Bright-1206-led-3/32623813733.html | CHIPLED_1206 | CHIPLED_1206 | LED
0.021 € | 0.021 € | 1 | 2 | D1 | BAV103 | SMD, diode, SOD80 | [picture](images/sod80_bav103.jpg) | sod80_bav103.jpg | gotron | SMD Si-diode 250V 200mA per 10st | https://www.gotron.be/signal-diode-smd-si-diode-250v-200ma-minimelf.html | BAV100-101-102-103 | SOD80_DO213AA_MINIMELF
0.025 € | 0.075 € | 3 | 4 | T1, T2, T3 | BC847C | SMD, NPN Transistor, SOT23 | [picture](images/sot23_bc847c.jpg) | sot23_bc847c.jpg | gotron | BC847C transistor SMD NPN 45V 0,5A 0,25W B:420-800 SOT23 (per 10st) | https://www.gotron.be/bc847c-transistor-smd-npn-45v-0-5a-0-25w-b-420-800-sot23.html | BC847 | SOT23 | 45 V, 100 mA NPN general-purpose transistors
0.090 € | 0.090 € | 1 | 1 | B1 | 5V | Through hole, buzzer, diameter 12mm, 0.3" (7.62mm) pin spacing | [picture](images/th_buzzer.jpg) | th_buzzer.jpg | conrad | 5V active buzzer 5V buzzer diameter 12MM* high 9.5MM long sound split 12095--DYDZ2 | https://www.aliexpress.com/item/5V-active-buzzer-5V-buzzer-diameter-12MM-high-9-5MM-long-sound-split-12095-DYDZ2/32693845475.html | Buzzer | Diameter 12mm, 0.3" (7.62mm) pin spacing
1.800 € | 1.800 € | 1 | 1 | U1 | ESP12E | SMD, ESP12E module | [picture](images/esp12e.jpg) | esp12e.jpg | aliexpress | 2015 New version 1PCS ESP-12F (ESP-12E upgrade) ESP8266 remote serial Port WIFI wireless module | https://www.aliexpress.com/item/2015-New-version-1PCS-ESP-12F-ESP-12E-upgrade-ESP8266-remote-serial-Port-WIFI-wireless-module/32643052680.html | ESP8266(ESP12E)SMD | ESP8266(ESP12E) | ESP12E Module
0.710 € | 0.710 € | 1 | 1 | U2 | LM3940 | SMD, Low drop voltage regulator, SOT223 | [picture](images/sot223_lm3940.jpg) | sot223_lm3940.jpg | aliexpress | 20pcs LM3940IMPX-3.3 LM3940IMPX LM3940 L52B Manu: NS Encapsulation: SOT-223 | https://www.aliexpress.com/item/20pcs-LM3940IMPX-3-3-LM3940IMPX-LM3940-L52B-Manu-NS-Encapsulation-SOT-223/32368826022.html | LM3940 | SOT223
2.340 € | 2.340 € | 1 | 1 | U3 | HLK-PM01 | Through hole, power module, HiLink HLK-PM01 | [picture](images/th_hlk-pm01.jpg) | th_hlk-pm01.jpg | aliexpress | 10 pcs HLK-PM01 AC-DC 220V to 5V Step-Down Buck Power Supply Module Intelligent Household Switch Power Supply Module 2015 New! | https://www.aliexpress.com/item/HLK-PM01-AC-DC-220V-to-5V-Step-Down-Power-Supply-Module-Intelligent-Household-Switch-Power/32267470516.html | HLK-PM01 | HLK-PM01
0.111 € | 0.111 € | 1 | 1 | J1 | FTDI | Through hole, header female, 6P, 0.1" (2.54mm) pin spacing | [picture](images/th_ftdi.jpg) | th_ftdi.jpg | aliexpress | 20Pcs/lot High Quality 1*6P 2.54mm Pitch 6 Pin Female Single Row Straight Header Strip | https://www.aliexpress.com/item/20Pcs-lot-freeshipping-1-6P-2-54mm-Pitch-6-Pin-Female-Single-Row-Straight-Header-Strip/32451125772.html | FTDI | FTDI
0.036 € | 0.072 € | 2 | 2 | S1, S2 | PROG, RST | SMD Push button | [picture](images/micropushbutton.jpg) | micropushbutton.jpg | aliexpress | 100PCS 3*6*2.5 mm 3*6*2.5 mm 3*6*2.5H SMD White Button switch key switch Tact Switch | https://www.aliexpress.com/item/100PCS-3-6-2-5-mm-3-6-2-5-mm-3-6-2-5H-SMD/32246843196.html | PUSHBTN | SMDPUSHBTN_TYPE1
0.340 € | 0.340 € | 1 | 1 | S3 | SRD-05VDC-SL-C | Through hole, Relay SRD-05VDC-SL-C | [picture](images/relay.jpg) | relay.jpg | aliexpress | 10PCS RELAY 5V SRD-5VDC-SL-C T73-5V Power Relay NEW GOOD QUALITY | https://www.aliexpress.com/item/10PCS-RELAY-5V-SRD-5VDC-SL-C-T73-5V-SONGLE-Power-Relay-NEW-GOOD-QUALITY/32444108945.html | SRD-05VDC-SL-CPTH | SRD-05VDC-SL-C | SONGLE RELAY SRD-05VDC-SL-C
0.014 € | 0.028 € | 2 | 2 | PIR, SW | XH3P | Through hole, Connector male XH3P straight | [picture](images/th_xh3pmale.jpg) | th_xh3pmale.jpg | aliexpress | XH2.54mm connector straight pin XH-2P/3P/4P/5P/6P/7P/8P/9P/10P/11P/12P Socket Terminals connector for PCB | https://www.aliexpress.com/item/XH2-54mm-connector-straight-pin-XH-2P-3P-4P-5P-6P-7P-8P-9P-10P-11P/32759275972.html | XH3P | XH3P
1.536 € | 1.536 € | 1 | 1 | DS18B20 temp sensor encased |  | Module, DS18B20 temp sensor encased | [picture](images/ds18b20.jpg) | ds18b20.jpg | aliexpress | J34 10 pcs/lot Wholesale&Retail High Quality Waterproof Digital Temperature Temp Sensor Thermal Probe DS18B20 Free Shipping | https://www.aliexpress.com/item/J34-10-pcs-lot-Wholesale-Retail-High-Quality-Waterproof-Digital-Temperature-Temp-Sensor-Thermal-Probe-DS18B20/32600424541.html
0.998 € | 0.998 € | 1 | 1 | PIR Module |  | Module, PIR | [picture](images/pirmodule.jpg) | pirmodule.jpg | aliexpress | 86076 Free Shipping 5pcs SR501 HC-SR501 Adjust IR Pyroelectric Infrared PIR module Motion Sensor Detector Module | https://www.aliexpress.com/item/15925-Free-Shipping-SR501-HC-SR501-Adjust-IR-Pyroelectric-Infrared-PIR-module-Motion-Sensor-Detector-Module/32354930080.html
2.081 € | 2.081 € | 1 | 1 | Switch with led |  | Switch with led | [picture](images/pushbutton.jpg) | pushbutton.jpg | aliexpress | 1202 Domed plastic momentary dot light Pin terminal illuminated pushbutton switch | https://www.aliexpress.com/item/1202-Domed-plastic-momentary-dot-light-Pin-terminal-illuminated-pushbutton-switch/32303825663.html
0.050 € | 0.100 € | 2 | 2 | XH3P female no pins |  | XH3P female no pins | [picture](images/xh3pfemalesolder.jpg) | xh3pfemalesolder.jpg | aliexpress
0.040 € | 0.080 € | 2 | 2 | XH3P wire 10cm [pin -> solder], black |  | XH3P wire 10cm [pin -> solder], black | [picture](images/xh3pfemalesolder.jpg) | xh3pfemalesolder.jpg | aliexpress | New 6-Colors XH2.54 Single Tin Header 10CM/20CM/30CM Terminal wire Connector wire 26AWG | https://www.aliexpress.com/item/New-6-Colors-XH2-54-Single-Tin-Header-10CM-20CM-30CM-Terminal-wire-Connector-wire-26AWG/32727154093.html
0.040 € | 0.080 € | 2 | 2 | XH3P wire 10cm [pin -> solder], red |  | XH3P wire 10cm [pin -> solder], red | [picture](images/xh3pfemalesolder.jpg) | xh3pfemalesolder.jpg | aliexpress | New 6-Colors XH2.54 Single Tin Header 10CM/20CM/30CM Terminal wire Connector wire 26AWG | https://www.aliexpress.com/item/New-6-Colors-XH2-54-Single-Tin-Header-10CM-20CM-30CM-Terminal-wire-Connector-wire-26AWG/32727154093.html
0.040 € | 0.040 € | 1 | 1 | XH3P wire 10cm [pin -> solder], yellow |  | XH3P wire 10cm [pin -> solder], yellow | [picture](images/xh3pfemalesolder.jpg) | xh3pfemalesolder.jpg | aliexpress | New 6-Colors XH2.54 Single Tin Header 10CM/20CM/30CM Terminal wire Connector wire 26AWG | https://www.aliexpress.com/item/New-6-Colors-XH2-54-Single-Tin-Header-10CM-20CM-30CM-Terminal-wire-Connector-wire-26AWG/32727154093.html
0.040 € | 0.040 € | 1 | 1 | XH3P wire 10cm [pin -> solder], white |  | XH3P wire 10cm [pin -> solder], yellow | [picture](images/xh3pfemalesolder.jpg) | xh3pfemalesolder.jpg | aliexpress | New 6-Colors XH2.54 Single Tin Header 10CM/20CM/30CM Terminal wire Connector wire 26AWG | https://www.aliexpress.com/item/New-6-Colors-XH2-54-Single-Tin-Header-10CM-20CM-30CM-Terminal-wire-Connector-wire-26AWG/32727154093.html
15.850 € | 15.850 € | 1 | 1 | Case |  | Case BOPLA 43432501, predrilled | [picture](images/case.jpg) | case.jpg | conrad | Bopla 43432501 Stekkerbehuizing 120 x 65 x 50 Kunststof Lichtgrijs 1 stuks | http://www.conrad.be/ce/nl/product/522228/Bopla-43432501-Stekkerbehuizing-120-x-65-x-50-Kunststof-Lichtgrijs-1-stuks/SHOP_AREA_14740
8.990 € | 8.990 € | 1 | 1 | PCB |  | Custom PCB | [picture](images/pcb.jpg) | pcb.jpg | eurocircuits
0.045 € | 0.090 € | 2 | 2 | Cable lug round M3 |  | Cable lug round M3 | [picture](images/cablelugroundm3.jpg) | cablelugroundm3.jpg | gotron | Oog M3 Rood - 100 stuks | https://www.gotron.be/oog-m3-rood-100-stuks.html
0.045 € | 0.045 € | 1 | 1 | Cable lug fork M4 |  | Cable lug fork M4 | [picture](images/cablelugforkm4.jpg) | cablelugforkm4.jpg | gotron | Vork M4 Rood - 100 stuks | https://www.gotron.be/vork-m4-rood-100-stuks.html
1.000 € | 1.000 € | 1 | 1 | Heat shrink tubing 1,5, 2.5mm, 6mm, 8mm |  | Heat shrink tubing 1,5, 2.5mm, 6mm, 8mm | [picture](images/heatshrinktubing.jpg) | heatshrinktubing.jpg | gotron
0.050 € | 0.150 € | 3 | 3 | PCB Fixation screw |  | Allen screw, inox, M3 x 6mm thread length | [picture](images/screw.jpg) | screw.jpg
0.050 € | 0.050 € | 1 | 1 | 1.5mm2 x 55mm mains wire brown |  | 1.5mm2 x 55mm mains wire brown | [picture](images/mainswire.jpg) | mainswire.jpg
0.050 € | 0.050 € | 1 | 1 | 1.5mm2 x 55mm mains wire blue |  | 1.5mm2 x 55mm mains wire blue | [picture](images/mainswire.jpg) | mainswire.jpg
0.050 € | 0.050 € | 1 | 1 | 1.5mm2 x 55mm mains wire yellow/green |  | 1.5mm2 x 55mm mains wire yellow/green | [picture](images/mainswire.jpg) | mainswire.jpg
10.000 € | 10.000 € | 1 |  | shipping
excl | 47.702 €
incl | 57.720 €
marge | 50.7281542%
 | 87.000 €
 | 29.28 €
10.00 | 292.802 €
50.00 | 1464.010 €
100.00 | 2928.019 €
not included
 | just solder | 1 |  | J2 | HIGHCURRENTCON6PSOLDER |  |  |  |  |  |  | HIGHCURRENTCON6PSOLDER | HIGHCURRENTCON6P_SOLDER
 | expansion header will not include | 1 |  | EXT | HEADER4P2X2P | Header female 2x2P, 0.1" (2.54) pin spacing |  |  |  |  |  | HEADER4P2X2P | HEADER2X2P
 | solder directly on board otherwise req to crimp conn on leads | 1 |  | DS18B20 | XH3P

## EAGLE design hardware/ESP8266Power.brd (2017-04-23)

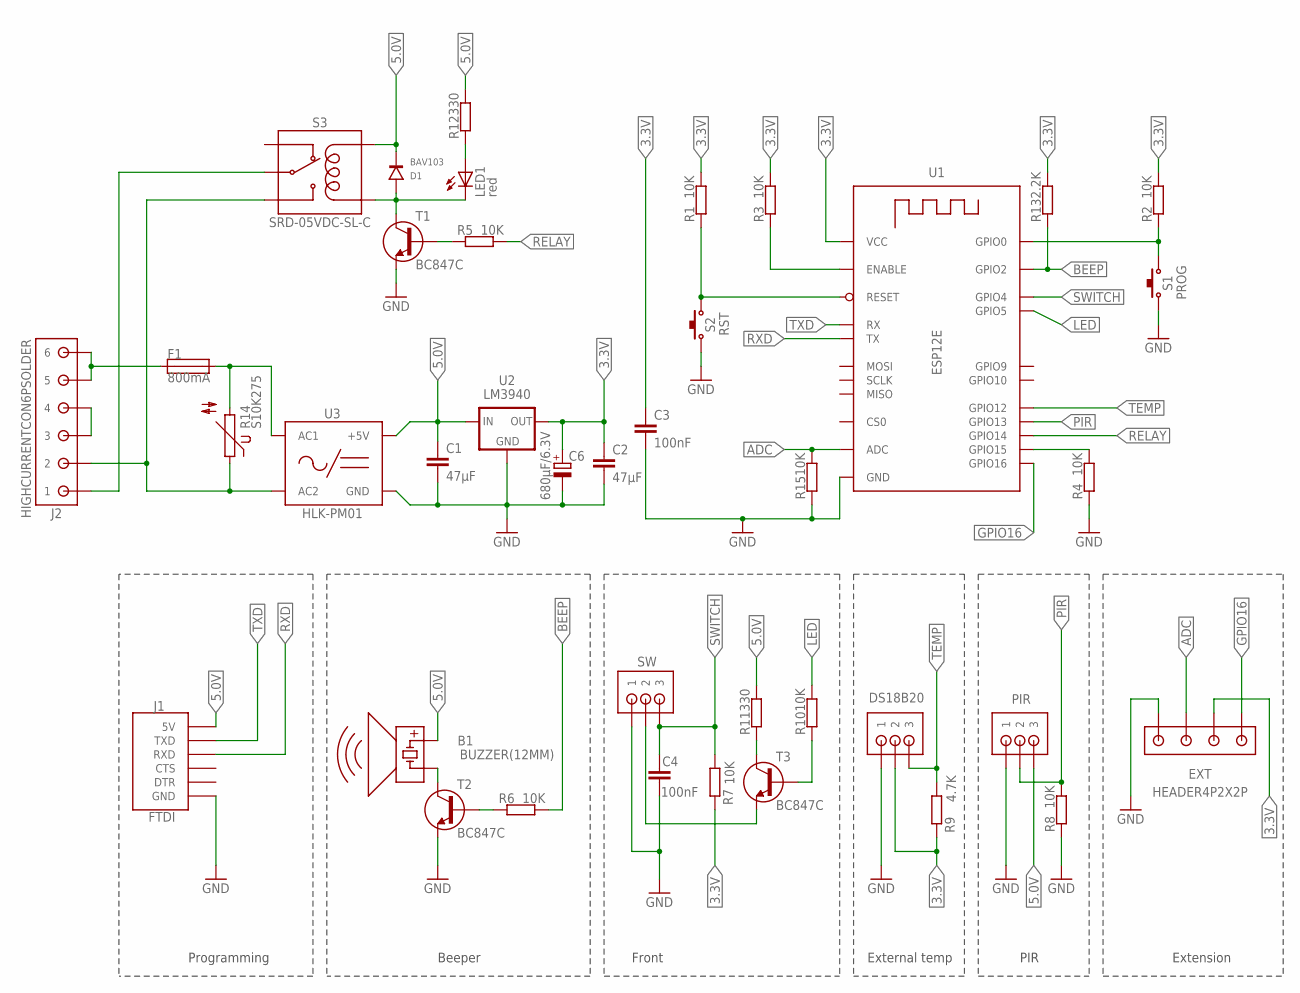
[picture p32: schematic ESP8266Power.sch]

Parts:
B1: BUZZER(12MM)
C1, C2: 47μF; C1206
C3, C4: 100nF; C1206
C6: 680μF/6.3V; E3,5-8
D1: BAV103; SOD80_DO213AA_MINIMELF
DS18B20: XH3P
EXT: HEADER4P2X2P; HEADER2X2P
F1: 800mA; FUSE_508
J1: FTDI
J2: HIGHCURRENTCON6PSOLDER; HIGHCURRENTCON6P_SOLDER
LED1: red; CHIPLED_1206
PIR: XH3P
R1, R2, R3, R4, R5, R6, R7, R8, R10, R15: 10K; R1206
R9: 4.7K; R1206
R11, R12: 330; R1206
R13: 2.2K; R1206
R14: S10K275
S1: PROG; SMDPUSHBTN_TYPE1
S2: RST; SMDPUSHBTN_TYPE1
S3: SRD-05VDC-SL-C
SW: XH3P
T1, T2, T3: BC847C; SOT23
U1: ESP12E; ESP8266(ESP12E)
U2: LM3940; SOT223
U3: HLK-PM01

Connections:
3.3V: C2.1, C3.1, C6.+, DS18B20.2, EXT.2, R1.2, R2.2, R3.2, R7.2, R9.2, R13.2, U1.VCC, U2.3 (OUT)
5.0V: B1.+, C1.1, D1.C, J1.5V, PIR.3, R11.2, R12.2, S3.COIL1, U2.1 (IN), U3.VO+ (+5V)
AC1: F1.2, R14.2, U3.AC1
AC2: J2.2, R14.1, S3.SW-NORMAL_OPEN, U3.AC2
ADC: EXT.3, R15.2, U1.ADC
BEEP: R6.2, R13.1, U1.GPIO2
EARTH: J2.3, J2.4
ENABLE: R3.1, U1.CH_PD (ENABLE)
GND: C1.2, C2.2, C3.2, C4.2, C6.-, DS18B20.1, EXT.4, J1.GND, PIR.1, R4.1, R8.1, R15.1, S1.2, S2.2, SW.1, T1.2 (E), T2.2 (E), U1.GND, U2.2 (GND), U2.4 (GND), U3.VO- (GND)
GPIO0: R2.1, S1.1, U1.GPIO0
GPIO15: R4.2, U1.GPIO15
GPIO16: EXT.1, U1.GPIO16
LED: R10.2, U1.GPIO5
LOAD: J2.1, S3.SW-COMMON
unnamed: R5.1, T1.1 (B)
unnamed: D1.A, LED1.C, S3.COIL0, T1.3 (C)
unnamed: R6.1, T2.1 (B)
unnamed: B1.-, T2.3 (C)
unnamed: R10.1, T3.1 (B)
unnamed: R11.1, T3.3 (C)
unnamed: SW.2, T3.2 (E)
unnamed: LED1.A, R12.1
unnamed: F1.1, J2.5, J2.6
PIR: PIR.2, R8.2, U1.GPIO13
RELAY: R5.2, U1.GPIO14
RESET: R1.1, S2.1, U1.RESET
RXD: J1.RXD, U1.TXD0 (TX)
SWITCH: C4.1, R7.1, SW.3, U1.GPIO4
TEMP: DS18B20.3, R9.1, U1.GPIO12
TXD: J1.TXD, U1.RXD0 (RX)

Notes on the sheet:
Front
Beeper
Programming
External temp
PIR
Extension

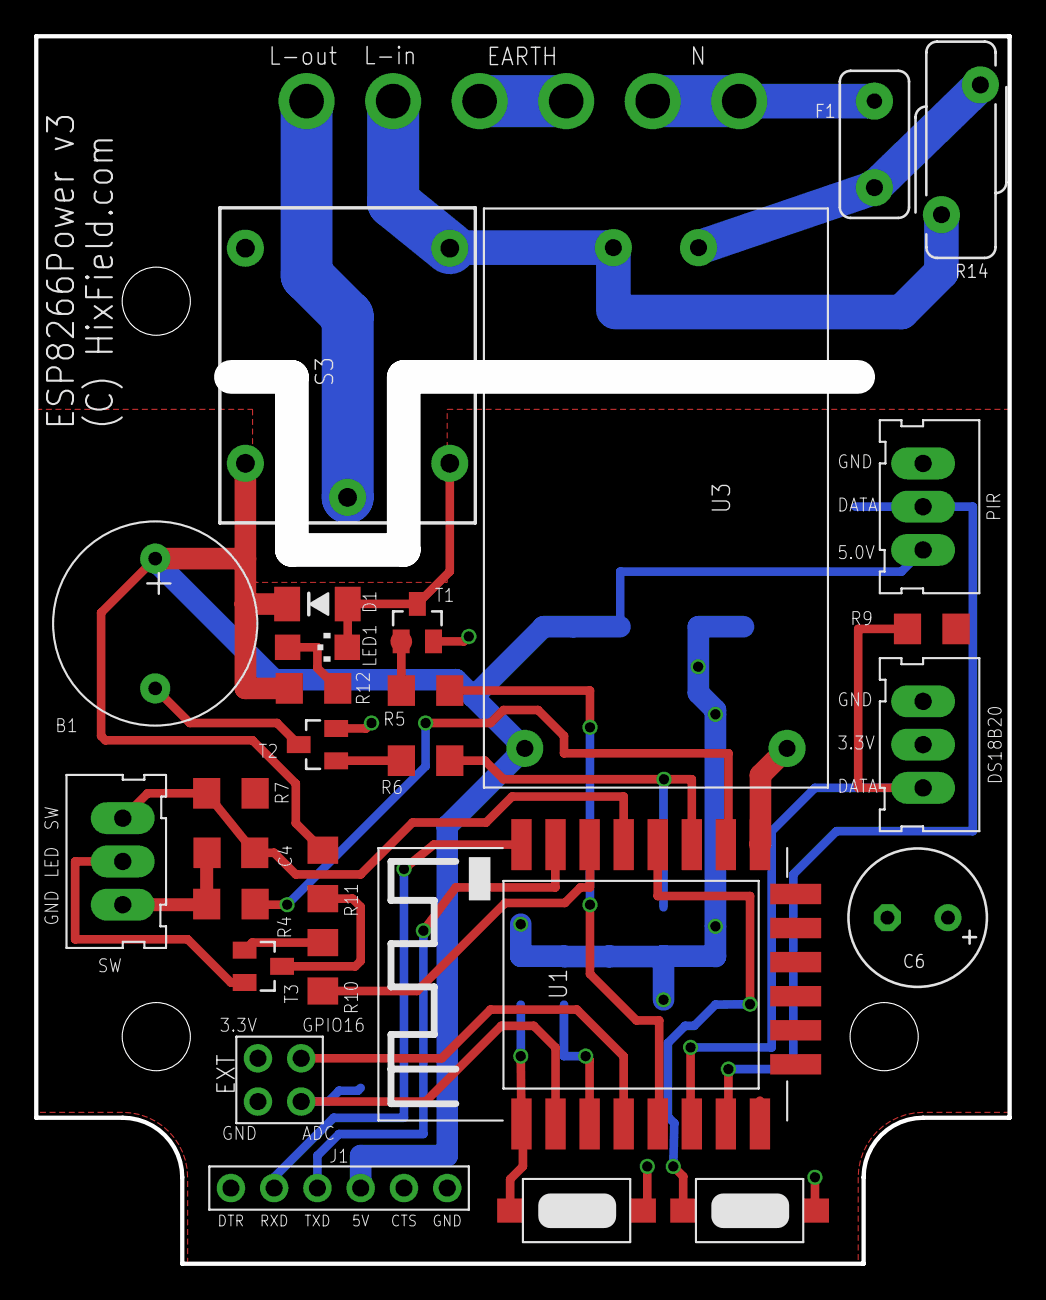
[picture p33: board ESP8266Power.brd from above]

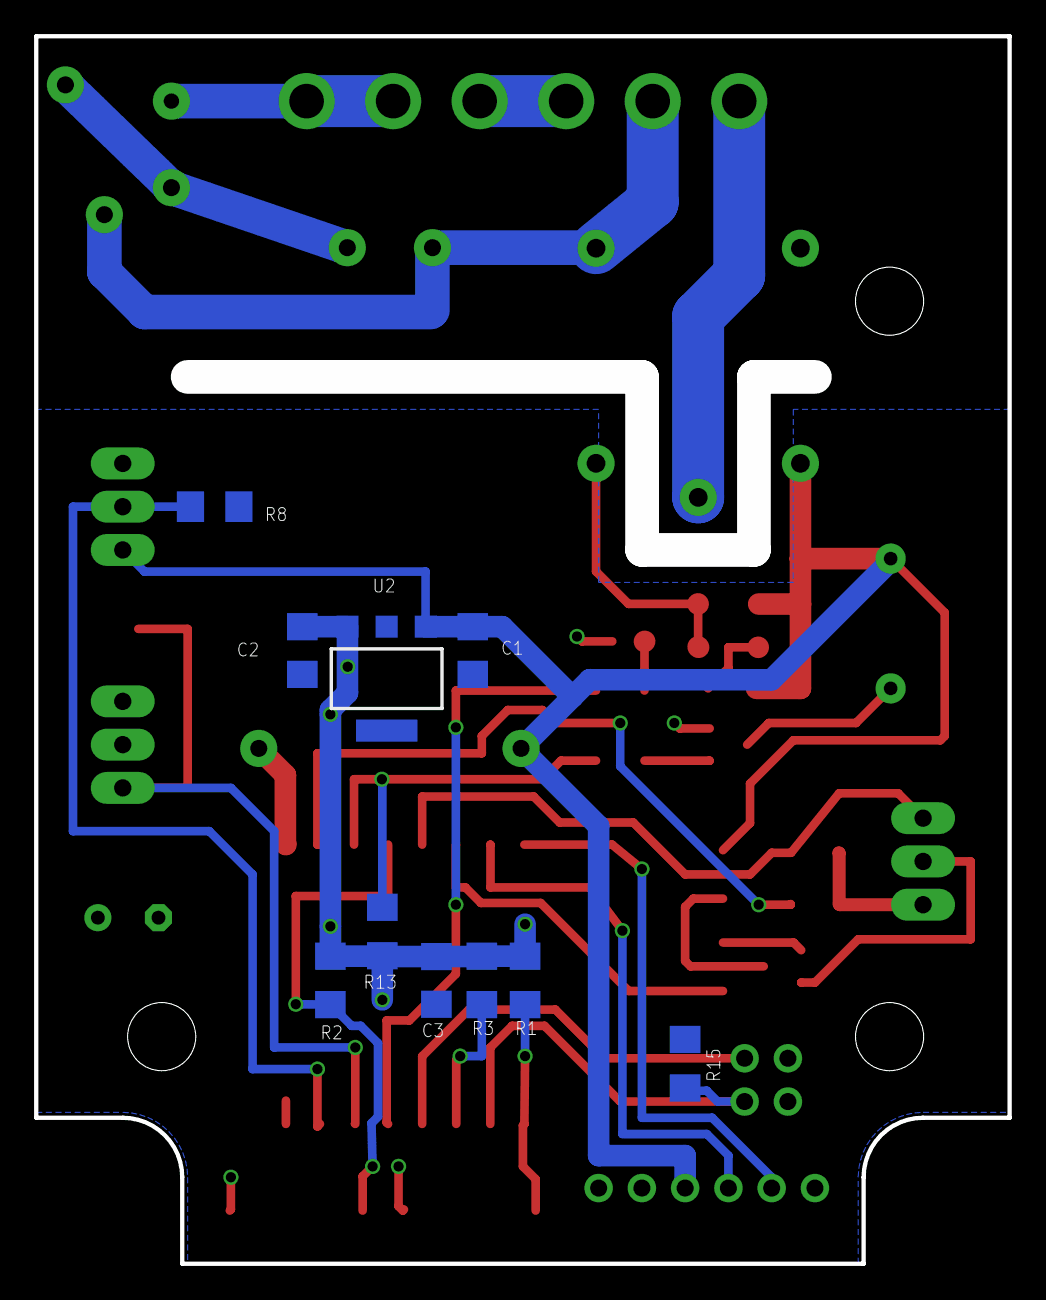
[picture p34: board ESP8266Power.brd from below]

Board: 2 copper layers, 57.1 x 72.1 mm, 39 parts (10 on the bottom side), 30 nets.

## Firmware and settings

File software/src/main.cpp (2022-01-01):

#include "HixConfig.h"
#include "HixDS18B20.h"
#include "HixMQTT.h"
#include "HixWebServer.h"
#include "secret.h"
#include <ArduinoOTA.h>
#include <FS.h>
#include <HixLED.h>
#include <HixPinDigitalInput.h>
#include <HixPinDigitalOutput.h>
#include <HixString.h>
#include <HixTimeout.h>

// runtime global variables
HixConfig    g_config;
HixWebServer g_webServer(g_config);
HixMQTT      g_mqtt(g_config,
               Secret::WIFI_SSID,
               Secret::WIFI_PWD,
               g_config.getMQTTServer(),
               g_config.getDeviceType(),
               g_config.getDeviceVersion(),
               g_config.getRoom(),
               g_config.getDeviceTag(),
               g_config.getDeviceBuildTimestamp());
// hardware related
HixPinDigitalOutput g_beeper(2);
HixPinDigitalOutput g_relay(14);
HixLED              g_led(5);
HixPinDigitalInput  g_motion(13);
HixPinDigitalInput  g_switch(4);
HixDS18B20          g_temperature(12);
// software related
HixTimeout    g_sampler(1000, true);
HixTimeout    g_logger(5000, true);
HixTimeout    g_buttonTimeout(500, true);
HixTimeout    g_motionTimeout(5000, true);
HixTimeout    g_relayTimeout(g_config.getAutoSwitchOffSeconds() * 1000, true);
volatile bool g_bLedBlinking = false;
// sensor values
float         g_fTemperature    = 0;
volatile bool g_bDetectedMotion = false;
volatile bool g_bPressedSwitch  = false;

//////////////////////////////////////////////////////////////////////////////////
// Helper functions
//////////////////////////////////////////////////////////////////////////////////

void configureOTA() {
    Serial.println("Configuring OTA, my hostname:");
    Serial.println(g_mqtt.getMqttClientName());
    ArduinoOTA.setHostname(g_mqtt.getMqttClientName());
    ArduinoOTA.setPort(8266);
    // setup handlers
    ArduinoOTA.onStart([]() {
        Serial.println("OTA -> Start");
    });
    ArduinoOTA.onEnd([]() {
        Serial.println("OTA -> End");
    });
    ArduinoOTA.onProgress([](unsigned int progress, unsigned int total) {
        Serial.printf("OTA -> Progress: %u%%\r", (progress / (total / 100)));
    });
    ArduinoOTA.onError([](ota_error_t error) {
        Serial.printf("OTA -> Error[%u]: ", error);
        if (error == OTA_AUTH_ERROR)
            Serial.println("OTA -> Auth Failed");
        else if (error == OTA_BEGIN_ERROR)
            Serial.println("OTA -> Begin Failed");
        else if (error == OTA_CONNECT_ERROR)
            Serial.println("OTA -> Connect Failed");
        else if (error == OTA_RECEIVE_ERROR)
            Serial.println("OTA -> Receive Failed");
        else if (error == OTA_END_ERROR)
            Serial.println("OTA -> End Failed");
    });
    ArduinoOTA.begin();
}

void resetWithMessage(const char * szMessage) {
    Serial.println(szMessage);
    delay(2000);
    ESP.reset();
}

void selfTest(void) {
    g_relay.blink(true, 5, 100);
    g_led.blink(true, 5, 100);
    g_beeper.blink(true, 5, 100);
}

bool heatingAllowed() {
    // if not running no heating allowed
    if (g_relayTimeout.isExpired()) {
        return false;
    }
    // ok, heating is allowed...
    // if we are currently on, keep heating until high temp reached
    if (g_relay.isHigh()) {
        return g_fTemperature < g_config.getSwitchOffTemperature();
    }
    // if currently off switch on if low temp reached
    return g_fTemperature < g_config.getSwitchOnTemperature();
}

bool handlePressedSwitch(void) {
    if (!g_bPressedSwitch) return false;
    g_bPressedSwitch = false;
    // debouncing
    if (g_buttonTimeout.isRunning()) {
        return false;
    }
    g_buttonTimeout.restart();
    // process command
    if (g_relayTimeout.isRunning()) {
        g_relayTimeout.invalidate();
    } else {
        g_relayTimeout.restart();
    }
    // handled something!
    return true;
}

bool handleDetectedMotion(void) {
    if (!g_bDetectedMotion) return false;
    g_bDetectedMotion = false;
    // debouncing
    if (g_motionTimeout.isRunning()) {
        return false;
    }
    g_motionTimeout.restart();
    // handled something!
    return true;
}

//////////////////////////////////////////////////////////////////////////////////
// ISR
//////////////////////////////////////////////////////////////////////////////////

ICACHE_RAM_ATTR void pressedSwitch(void) {
    g_bPressedSwitch = true;
}

ICACHE_RAM_ATTR void detectedMotion(void) {
    g_bDetectedMotion = true;
}

//////////////////////////////////////////////////////////////////////////////////
// Setup
//////////////////////////////////////////////////////////////////////////////////

void setup() {
    // print startup config
    Serial.begin(115200);
    Serial.print(F("Startup "));
    Serial.print(g_config.getDeviceType());
    Serial.print(F(" "));
    Serial.println(g_config.getDeviceVersion());
    // disconnect WiFi -> seams to help for bug that after upload wifi does not want to connect again...
    Serial.println(F("Disconnecting WIFI"));
    WiFi.disconnect();
    // init pins
    Serial.println(F("Setting up Beeper"));
    g_beeper.begin();
    Serial.println(F("Setting up Relay"));
    g_relay.begin();
    Serial.println(F("Setting up LED"));
    g_led.begin();
    // setup temp sensor
    Serial.println(F("Setting up temperature sensor"));
    if (!g_temperature.begin()) resetWithMessage("DS18B20 init failed, resetting");
    // configure MQTT
    Serial.println(F("Setting up MQTT"));
    if (!g_mqtt.begin()) resetWithMessage("MQTT allocation failed, resetting");
    // setup SPIFFS
    Serial.println(F("Setting up SPIFFS"));
    if (!SPIFFS.begin()) resetWithMessage("SPIFFS initialization failed, resetting");
    // setup the server
    Serial.println(F("Setting up web server"));
    g_webServer.begin();
    // hookup switch
    Serial.println(F("Hooking up the switch"));
    g_switch.attachInterrupt(pressedSwitch, FALLING);
    // hookup motion detector
    Serial.println(F("Hooking up the motion detector"));
    g_motion.begin();
    g_motion.attachInterrupt(detectedMotion, RISING);
    // all done
    Serial.println(F("Setup complete"));
}

//////////////////////////////////////////////////////////////////////////////////
// Loop
//////////////////////////////////////////////////////////////////////////////////

void loop() {
    // other loop functions
    g_mqtt.loop();
    g_webServer.handleClient();
    ArduinoOTA.handle();
    // isr handles & check if should do force publishing
    bool bHandledMotion = handleDetectedMotion();
    bool bHandledSwitch = handlePressedSwitch();
    if (bHandledSwitch) g_beeper.blink(true, 1, 150);
    bool bForcePublishing = bHandledMotion || bHandledSwitch;
    // now we calculated if we should forcepublishing we also set motion to true if its still high...
    bHandledMotion = bHandledMotion || g_motion.isHigh();
    // beep while motion detected
    // g_beeper.digitalWrite(bHandledMotion);
    // update relay
    g_relay.digitalWrite(heatingAllowed());
    // blink led if not connected
    if (g_mqtt.isConnected()) {
        // if allowed to heat
        if (g_relayTimeout.isRunning()) {
            // and we are actually heating
            if (g_relay.isHigh()) {
                g_led.on();
            }
            // no not heating must be to warm...
            else {
                g_led.fadeInOut();
            }
        }
        // not allow to heat switch off led
        else {
            g_led.off();
        }
    } else {
        g_led.fastBlink();
    }
    // my own processing
    if (g_sampler.isExpired(true) || bForcePublishing) {
        // load sensor values
        g_fTemperature = g_temperature.getTemp();
        // log to serial
        Serial.print(g_fTemperature);
        Serial.print(F(" C ; "));
        Serial.print(bHandledMotion);
        Serial.print(F(" B ; "));
        Serial.print(bHandledSwitch);
        Serial.print(F(" B ; "));
        Serial.print(g_beeper.isHigh());
        Serial.print(F(" B ; "));
        Serial.print(g_relayTimeout.isRunning());
        Serial.print(F(" B ; "));
        Serial.print(g_relay.isHigh());
        Serial.print(F(" B"));
        Serial.println();
    }
    if (g_logger.isExpired(true) || bForcePublishing) {
        g_mqtt.publishStatusValues(g_fTemperature, bHandledMotion, bHandledSwitch, g_beeper.isHigh(), g_relayTimeout.isRunning(), g_relay.isHigh(), g_relayTimeout.timeLeftMs() / 1000);
    }
}

//////////////////////////////////////////////////////////////////////////////////
// Required by the MQTT library
//////////////////////////////////////////////////////////////////////////////////

void onConnectionEstablished() {
    // setup OTA
    if (g_config.getOTAEnabled()) {
        configureOTA();
    } else {
        Serial.println("OTA is disabled");
    }

    // publish values
    g_mqtt.publishDeviceValues();
    g_mqtt.publishStatusValues(g_fTemperature, g_bDetectedMotion, g_bPressedSwitch, g_beeper.isHigh(), g_relayTimeout.isRunning(), g_relay.isHigh(), g_relayTimeout.timeLeftMs() / 1000);

    // register for display
    g_mqtt.subscribe(g_mqtt.topicForPath("subscribe/desired_temperature"), [](const String & payload) {
        g_config.setDesiredTemperature(payload.toFloat());
        g_config.commitToEEPROM();
        g_beeper.blink(1, 1, 10);
        g_mqtt.publishDeviceValues();
    });

    // register for beeper
    g_mqtt.subscribe(g_mqtt.topicForPath("subscribe/auto_switchoff_seconds"), [](const String & payload) {
        g_config.setAutoSwitchOffSeconds(payload.toInt());
        g_relayTimeout.updateTimeoutAndRestart(g_config.getAutoSwitchOffSeconds() * 1000);
        g_relayTimeout.invalidate();
        g_config.commitToEEPROM();
        g_beeper.blink(1, 1, 10);
        g_mqtt.publishDeviceValues();
    });

    // register for enable switching on
    g_mqtt.subscribe(g_mqtt.topicForPath("subscribe/output_toggle"), [](const String & payload) {
        pressedSwitch();
    });
}

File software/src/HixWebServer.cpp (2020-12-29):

#include "HixWebServer.h"
#include "secret.h"
#include <FS.h>

HixWebServer::HixWebServer(HixConfig & config) : ESP8266WebServer(80),
                                                 m_config(config) {
    onNotFound([this]() {
        if (!handleFileRead(uri()))
            send(404, "text/plain", "404: Not Found");
    });
}

String HixWebServer::getContentType(String filename) {
    if (filename.endsWith(".htm"))
        return "text/html";
    else if (filename.endsWith(".html"))
        return "text/html";
    else if (filename.endsWith(".css"))
        return "text/css";
    else if (filename.endsWith(".js"))
        return "application/javascript";
    else if (filename.endsWith(".png"))
        return "image/png";
    else if (filename.endsWith(".gif"))
        return "image/gif";
    else if (filename.endsWith(".jpg"))
        return "image/jpeg";
    else if (filename.endsWith(".ico"))
        return "image/x-icon";
    else if (filename.endsWith(".xml"))
        return "text/xml";
    else if (filename.endsWith(".pdf"))
        return "application/x-pdf";
    else if (filename.endsWith(".zip"))
        return "application/x-zip";
    else if (filename.endsWith(".gz"))
        return "application/x-gzip";
    return "text/plain";
}

bool HixWebServer::shouldReplacePlaceholders(String filename) {
    if (filename.endsWith(".htm")) return true;
    if (filename.endsWith(".html")) return true;
    return false;
}

// send the right file to the client (if it exists)
bool HixWebServer::handleFileRead(String path) {
    Serial.println("handleFileRead: " + path);
    //check for postback of config data
    if (path.endsWith("/postconfig")) {
        handlePostConfig();
        return true;
    }
    // If a folder is requested, send the index file
    if (path.endsWith("/")) path += "index.html";
    // Get the MIME type
    String contentType = getContentType(path);
    if (SPIFFS.exists(path)) {
        File file = SPIFFS.open(path, "r");
        if (shouldReplacePlaceholders(path)) {
            String contents = file.readString();
            m_config.replacePlaceholders(contents);
            //send it
            send(200, contentType, contents);
        } else {
            streamFile(file, contentType);
        }
        //close our input file
        file.close();
        //return non error
        return true;
    }
    //file not found
    return false;
}


bool HixWebServer::handlePostConfig(void) {
    //check password
    if (arg("password") != Secret::CONFIGPWD) {
        send(400, "text/plain", "Bad password");
        return false;
    }
    //handle parameters
    if (hasArg("mqtt_server")) m_config.setMQTTServer(arg("mqtt_server").c_str());
    if (hasArg("room")) m_config.setRoom(arg("room").c_str());
    if (hasArg("device_tag")) m_config.setDeviceTag(arg("device_tag").c_str());
    //write to epprom
    m_config.commitToEEPROM();
    //send reply
    const char * szSavedHtml = "/saved.html";
    File         file        = SPIFFS.open(szSavedHtml, "r");
    streamFile(file, getContentType(String(szSavedHtml)));
    file.close();
    //reset!
    delay(1000);
    ESP.reset();
    return true;
}

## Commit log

2017-04-23 hardware v3
    [ESP8266Power.brd, ESP8266Power.sch, bom.xlsx]
2017-05-07 added pcb assembly instructions
2017-05-08 added mains wires assembly instructions
2017-05-13 added instructions for push button
2017-05-13 corrected BOM
2017-05-14 added instructions for temp sensor and total assembling
2017-05-14 added buy button
2017-05-14 updated buy button
2017-06-13 updated pcb images
2017-06-13 corrected numbering errors for the resistors in the assembling instructions
2020-01-11 added power cable dimensions
2020-01-18 updated readme + fix OTA
    [main.cpp]
2020-02-10 fix issue saving to eeprom
    [main.cpp]
2020-04-03 fix to update timeout immediatly when recieved via MQTT (and not after reboot)
    [main.cpp]
2022-01-01 switched DS18B20 to arduino lib
2022-01-01 changing heat timeout now always shutsoff the heating as well
